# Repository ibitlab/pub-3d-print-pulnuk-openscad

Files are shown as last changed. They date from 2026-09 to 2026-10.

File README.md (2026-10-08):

**English** · [Українська](README.uk.md)

# Sealed enclosure for the KY-023 joystick

The KY-023 / HW-504 module costs a dollar and is open on every side: dust, dirt
and moisture go straight into the potentiometers. Here it lives in a closed box.
The only thing sticking out is the cap, and the motion is carried through a
printed TPU bellows boot that plugs the opening and re-centres the joystick at
the same time — the stock bell-shaped knob is no longer needed and comes off.

Fully parametric, a single OpenSCAD file, not one part needs supports.

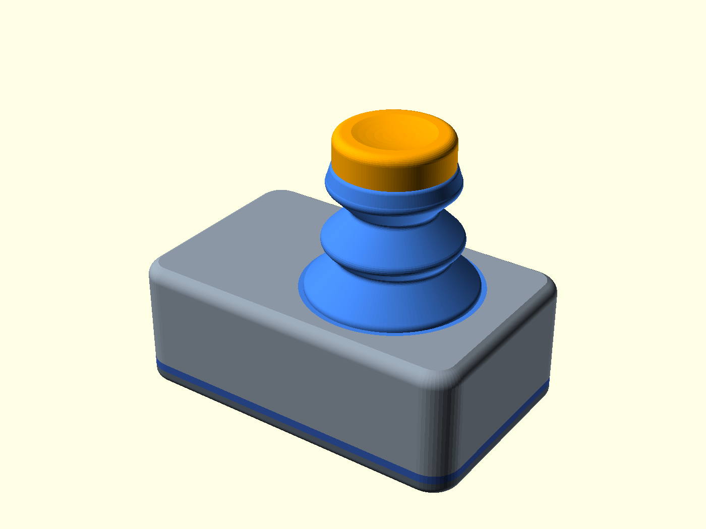
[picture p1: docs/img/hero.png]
Assembled enclosure


Box with lid: 62.4 × 39.1 × 23 mm, ≈53 mm tall including the cap.

| Printed and assembled on a KY-023 | The silicone mould, printed | TPU gasket and boot |
| --- | --- | --- |
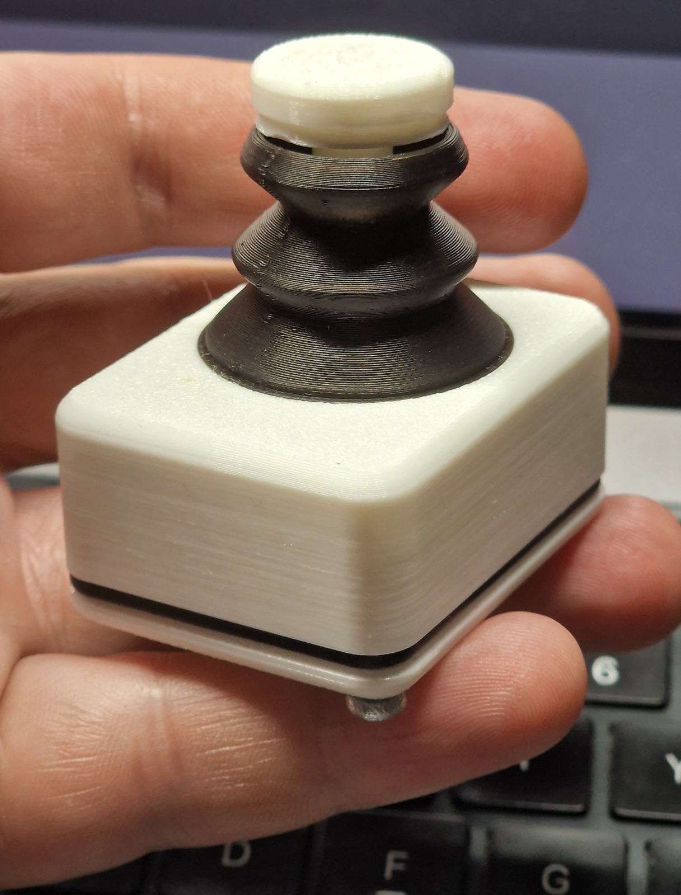
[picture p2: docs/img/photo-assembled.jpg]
The printed enclosure with the TPU boot and cap, in hand
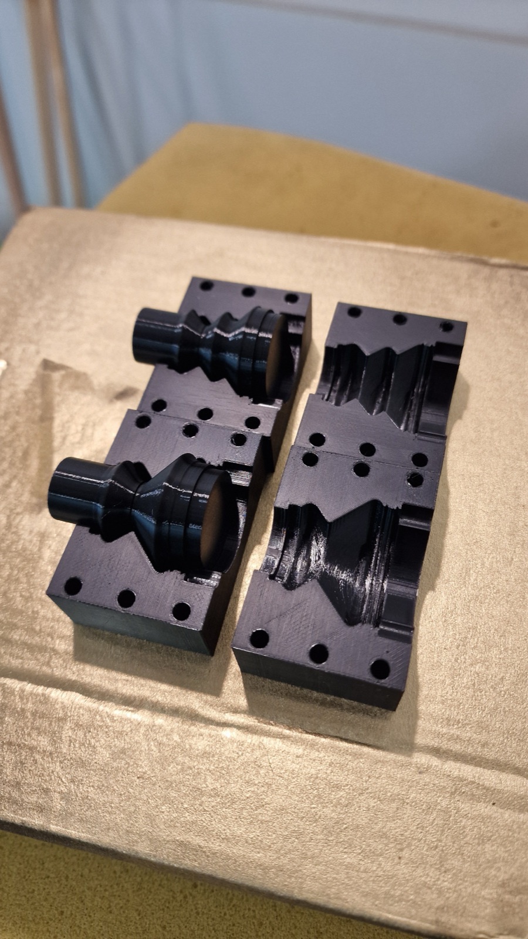
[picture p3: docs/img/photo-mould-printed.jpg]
The printed mould: shell halves and cores
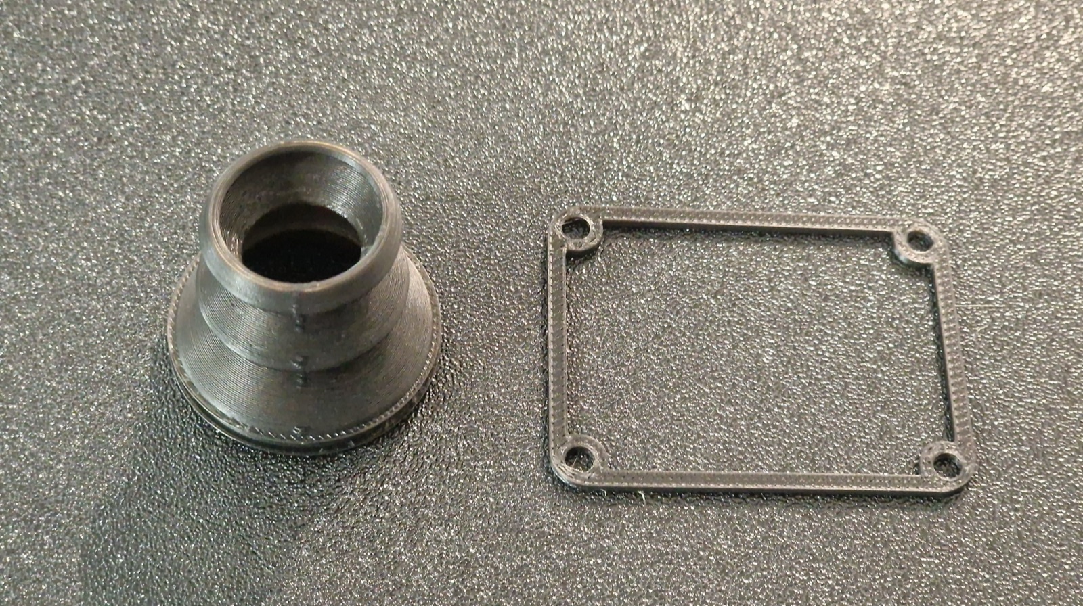
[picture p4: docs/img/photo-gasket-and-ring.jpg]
The printed TPU gasket and the boot with its expander ring
|  |  |  |

```
./render.sh     # every STL + PNG + the automatic checks, into versions/vNNN-.../
```

Next: **[PRINTING.md](PRINTING.md)** — printing, assembly, silicone casting ·
**[MODEL.md](MODEL.md)** — how it works and which parameters to turn.

---

## What's inside

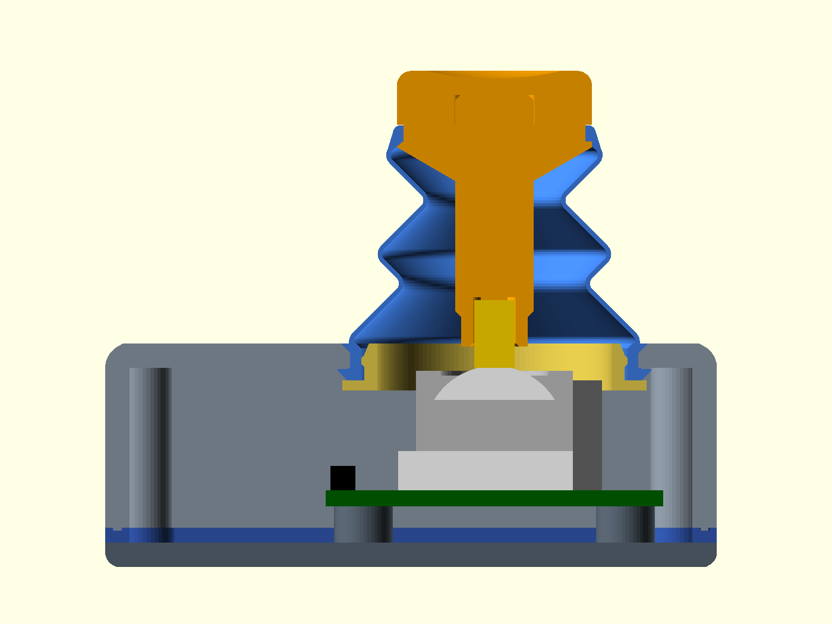
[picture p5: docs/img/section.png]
Section through the assembly


The PCB is screwed to standoffs on the **bottom** lid — lid and board go into the
box from below, so there is not a single screw and not a single joint on top.
Between the box rim and the lid sits a flat TPU gasket. The boot sits in the top
panel by its grommet, and is clamped at the top onto the groove of the cap stem.

Three joints, three different answers:

| Joint | What holds it |
|---|---|
| boot ↔ cap | a Ø1.6 bead stretched onto the stem groove with 6 % interference, covered by the glued-on head |
| boot ↔ box | the grommet cone seats into the panel countersink **flush** with it, the lip presses from below, and a rigid ring inside stops the grommet from pulling itself inward |
| box ↔ lid | a 0.8 × 0.5 rib on the box rim presses into the gasket groove; around each screw the rib is interrupted and the gasket is solid there |

Here is that grommet up close — the corrugation on the left, the expander ring in
yellow underneath, the box wall on the right:

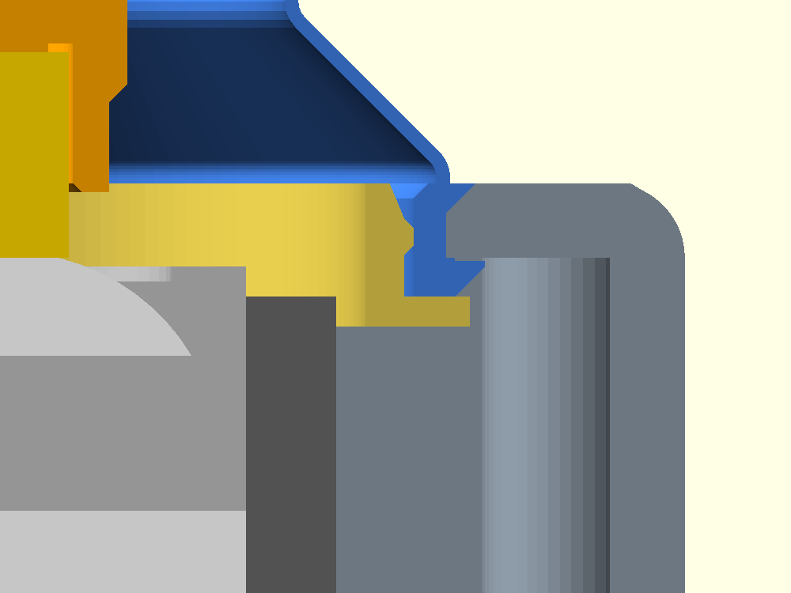
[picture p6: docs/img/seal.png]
Grommet in the panel


Nothing protrudes above the panel for anything to catch on.

## Why it re-centres

The boot is printed in exactly the shape it takes once installed, so its only
equilibrium is the centre. No spring required.

The whole trick is making it soft enough. The wall is printed in a **single nozzle
pass** — 0.46 mm, physically as thin as it gets — and stiffness grows as the cube
of thickness. The rest is down to the geometry of the folds: fold stiffness is
∝ 1/depth³, so one deep fold is softer than several shallow ones.

| `bellows = "v019"` — two folds | `bellows = "deep"` — one deep fold |
|---|---|
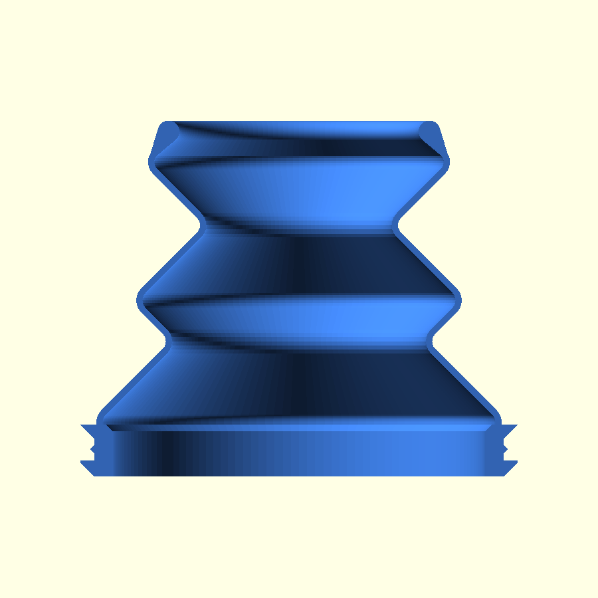
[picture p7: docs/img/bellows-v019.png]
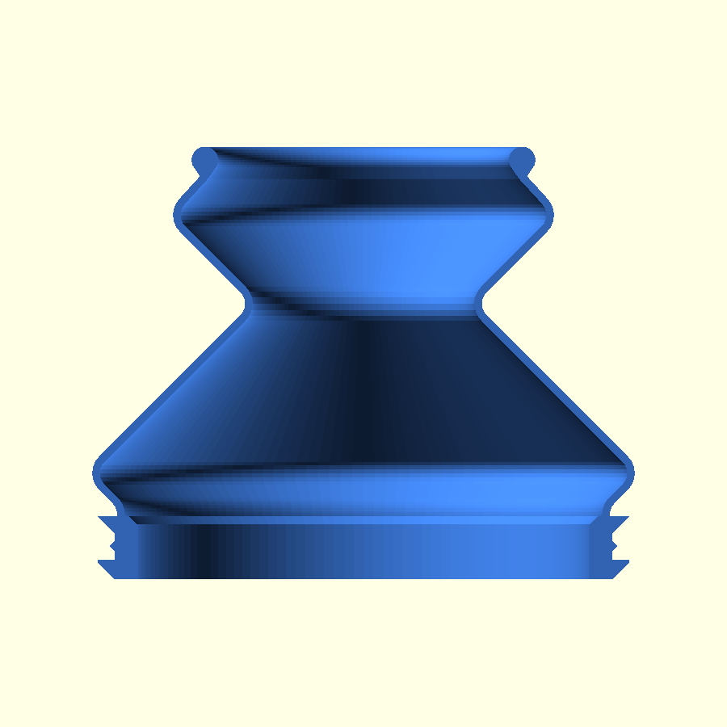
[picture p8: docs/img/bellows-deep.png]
|  |  |
| compliance index 0.46 · printed and verified on the module | index 0.91 — twice as soft on paper, not printed yet |

Both fit the same grommet, the same ring and the same stem groove — you can print
both and compare them on one module.

The model works this out itself and prints it to `ECHO` on every render:

```
ECHO: "Bellows "v019": meridian 27.9676 mm, rest chord 21.4529, last leg 33.4078 deg
       from vertical (keep <= 50), … compliance index 0.461043 (x 1/wall^3, higher = softer)"
ECHO: "At 25 deg: bead shifts 13.08 mm, … far-side stretch 3.95858 % (no stretch up to 21 deg)"
```

Up to 21° of tilt the far side of the boot only bends; stretch starts later and
reaches ~4 % at 25°. That is exactly why the bead is attached at the top of the
stem and not at the bottom, where the travel is half as long: those 13 mm of wall
length would cost 32 % stretch instead of 4, and stretch is no longer bending —
it is stiffness.

## Seven parts

| | | |
|---|---|---|
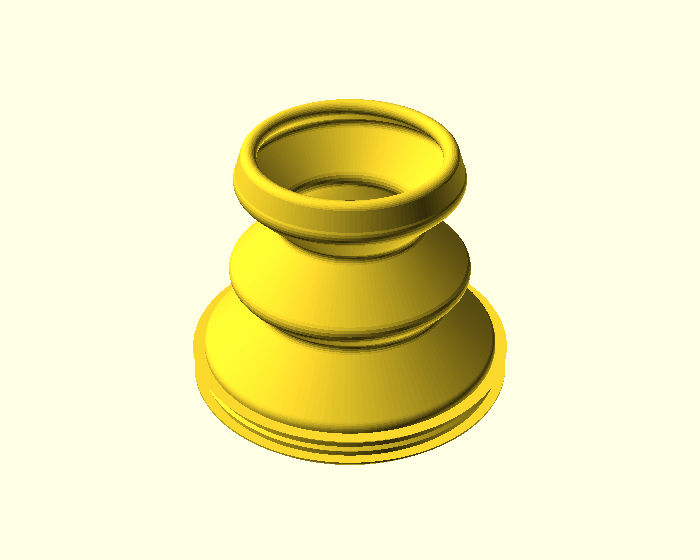
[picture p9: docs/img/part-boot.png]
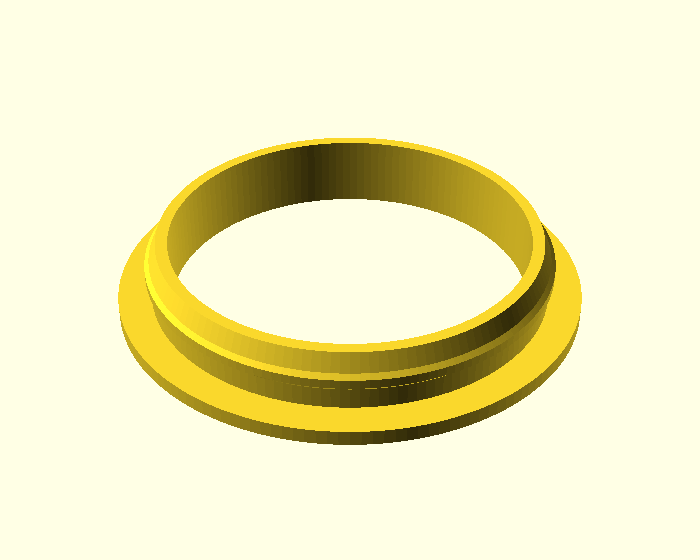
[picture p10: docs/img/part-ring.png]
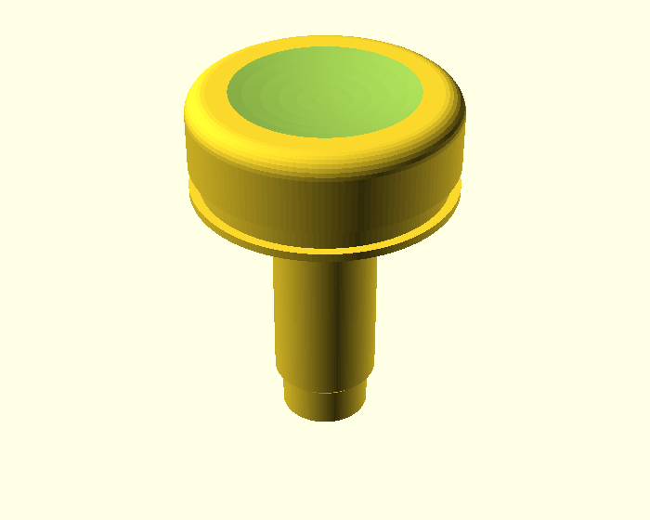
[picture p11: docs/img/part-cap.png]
|  **Boot with grommet** — TPU, single-pass wall |  **Expander ring** — goes into the grommet from inside |  **Cap** — head + stem, glued together |
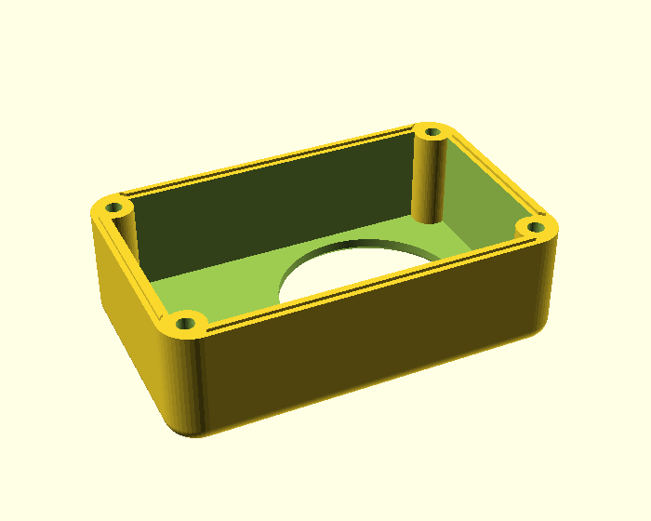
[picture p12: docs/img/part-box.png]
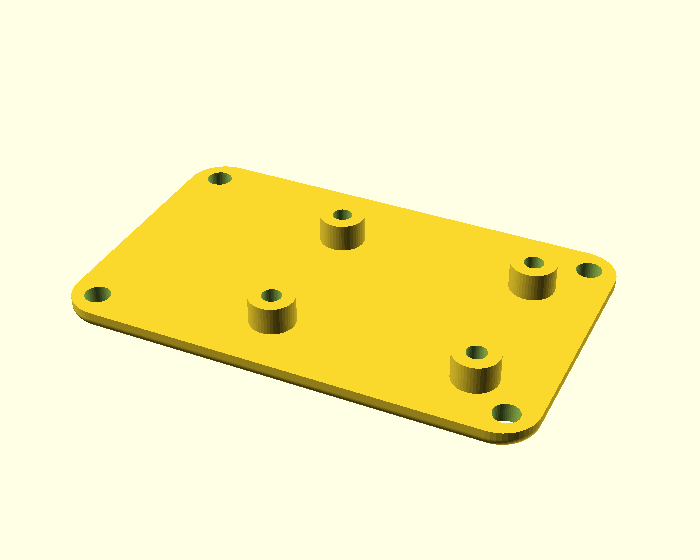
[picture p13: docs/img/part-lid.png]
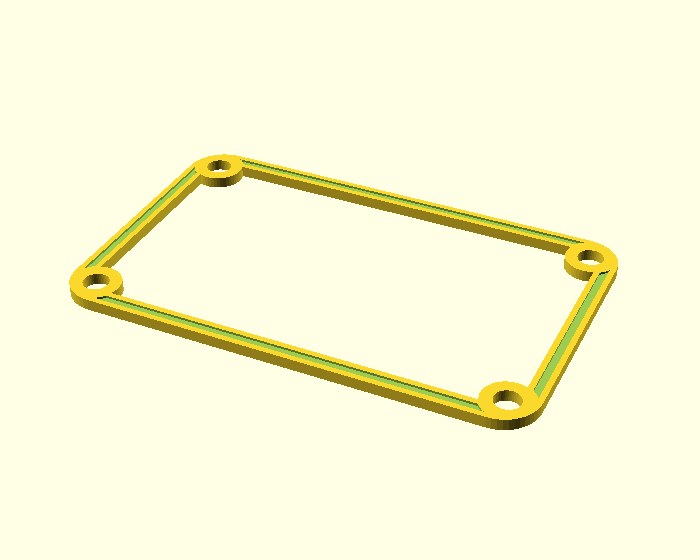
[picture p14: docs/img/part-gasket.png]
|  **Box** — sealing rib on the rim, 4 bosses |  **Lid** — PCB standoffs, enters from below |  **Gasket** — TPU, groove for the rib |

Plus a mock-up of the board — not for printing, it is there to check the joystick
and hole positions against your own module on screen:

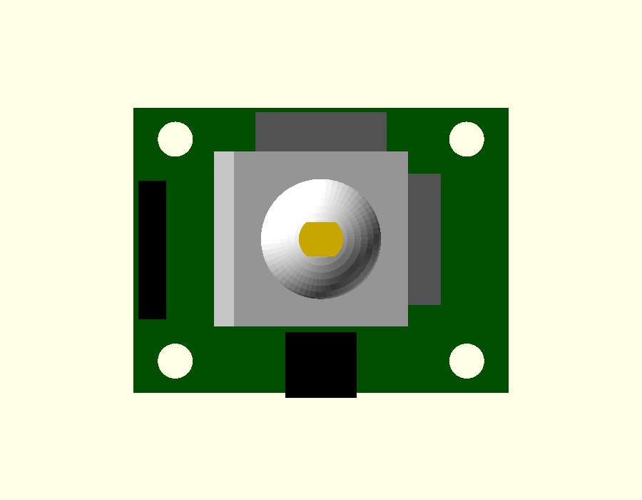
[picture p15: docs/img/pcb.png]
PCB mock-up


## Silicone instead of TPU

The printed TPU boot seals and re-centres, but in use it turned out too stiff
for this job, and a printed boot cannot get thinner than its 0.46 mm wall.
Silicone gets around that with the material instead: A20 is roughly 50 times
softer than TPU 95A, so even a 1.2 mm wall gives a boot about three times
softer. The geometry stays the same, so the next step is a boot cast in
platinum-cure silicone.

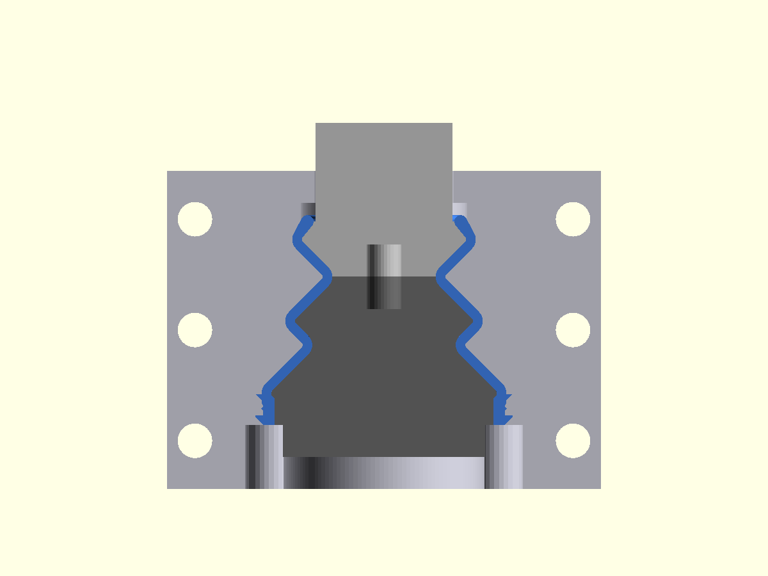
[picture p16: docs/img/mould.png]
Section through the mould


The mould is generated from the same model: two **identical** shell halves
(everything on the parting plane comes in ±X pairs, so one half rotated 180° is
the other), a core split at the waist of the corrugation — it cannot be pulled out
in one piece, being a barrel between two narrower openings — and pins. It is cast
bottom-up with a syringe: gravity will not fill a 1.2 mm annular gap over 28 mm of
height.

Procedure and quantities for silicone are in [PRINTING.md](PRINTING.md). The mould
is printed (photo at the top); the first cast is pending.

## How it grew

Same camera throughout, sources from `versions/` — a copy of the `.scad` for every
render lives there.

| v001 | v005 | v006 |
|---|---|---|
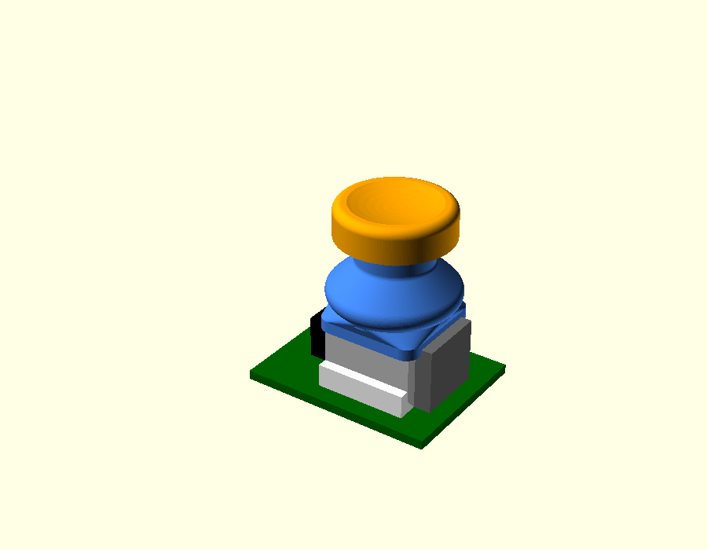
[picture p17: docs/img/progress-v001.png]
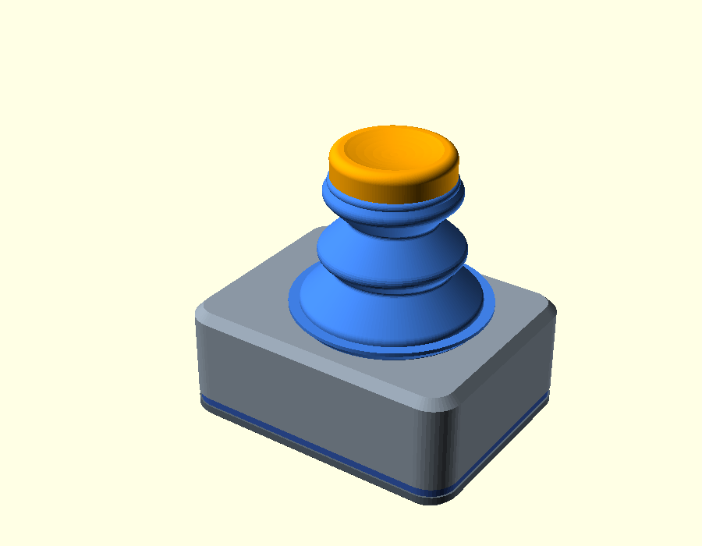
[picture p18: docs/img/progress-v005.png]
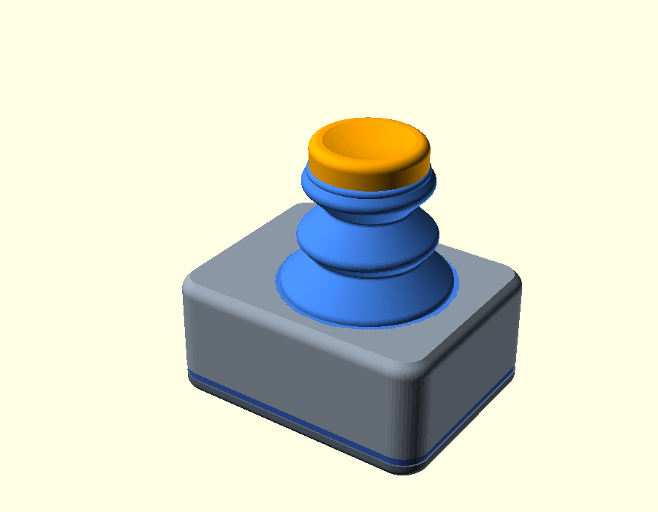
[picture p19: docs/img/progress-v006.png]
|  |  |  |
| Just an open boot over the joystick frame. No box yet, and no sealing either. | A grommet in the panel instead of a clamped sheet, lid moved to the bottom — no more screws on top. | **Printed.** The grommet cone seats into the countersink flush with the panel; the expander ring and the rounded edges appear. |

| v019 | now |
|---|---|
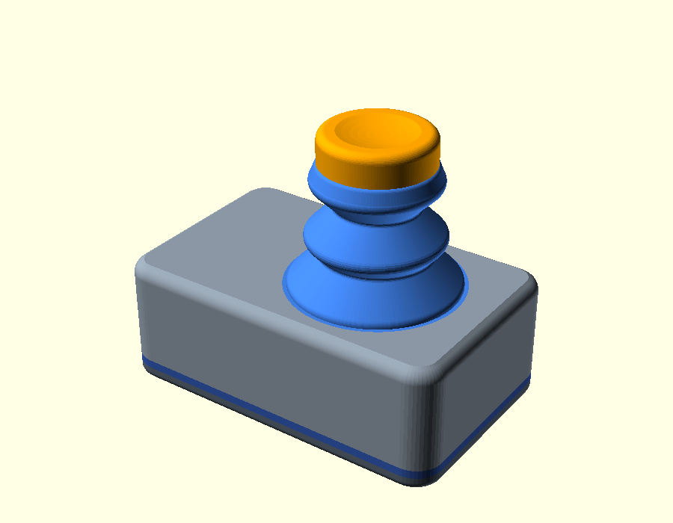
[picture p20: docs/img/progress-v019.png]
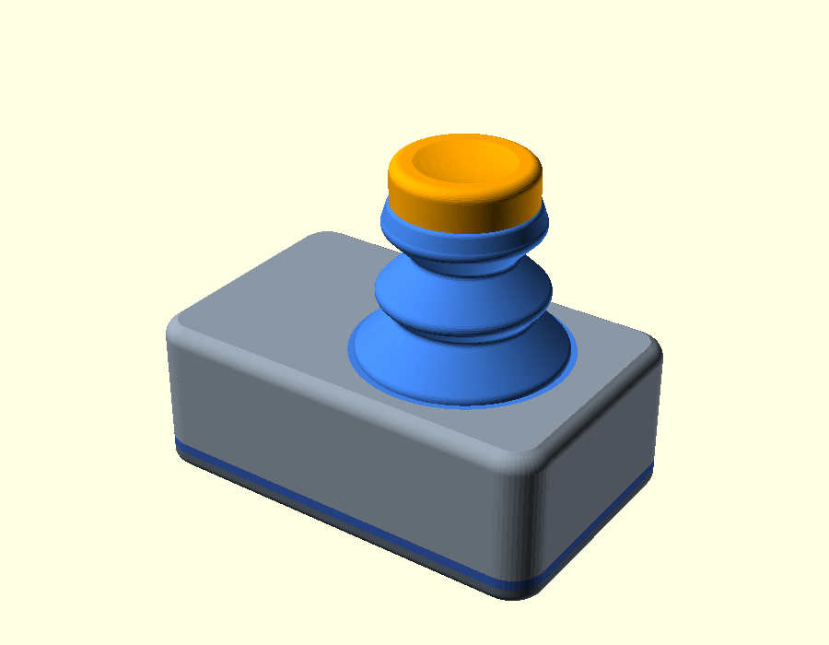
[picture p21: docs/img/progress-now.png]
|  |  |
| **Printed.** Measured joystick position on the board, two-part cap, bead moved onto the stem flange. | Two bellows profiles to choose from, a mould for casting, mesh checking on every render. |

The full history with the reasoning is at the end of [MODEL.md](MODEL.md).

## How this is verified

A render that looks right in a PNG proves nothing. So every `./render.sh` ends
with checks, and three more are run by hand:

| | |
|---|---|
| `check_mesh.py` | every STL must be **one closed body**: each edge in exactly two triangles, one body |
| `check_overhang.py` | slices the profile in 0.1 mm layers: islands, overhangs > 45°, cross-sections thinner than a slicer line |
| `check_fit.scad` | seven boolean tests of the mould — each exports what should not exist; ~0 mm³ should be left |
| `stl_volume.py` | volume, area and mean thickness 2·V/A — for a remainder that should have been zero, it is the thickness that matters, not the volume |
| `compare_versions.sh` | compares the STLs of two renders byte for byte: a part you did not touch must stay byte-identical |

This is not a formality. Two examples that brought these checks into being:

- **v021.** The boot wall was made a single 0.40 mm pass. The slicer silently
  dropped it at the bends, where the cross-section turns vertical, and empty
  layers appeared in the part. The cure is to model a single-pass wall as the
  slicer line width + 0.04 = 0.46 — and the `minw` check in `check_overhang.py`.
- **v026.** The mould shell would not slice, the slicer complained about
  non-manifold edges. The cause: the surface shared by the part and the core is
  drawn by different code — the wall by 24-gons, the core by true `offset()` arcs
  — and on the fold radii the two drifted apart by ~5 µm. Those slivers got
  pinched inside the cavity and left free 5 µm-thick rings in the shell. Invisible
  in a PNG, invisible in the volume. Hence `check_mesh.py` on every render.

And `compare_versions.sh` is the only honest way to tell "I rewrote the code" from
"I moved the geometry": neither a PNG nor a triangle count will tell you that.

## Status, honestly

- **Printed and assembled:** `v006` and `v019`. The default bellows profile is the
  one that is on the real module.
- **Not verified in plastic:** the `deep` bellows.
- **Printed, casting pending:** the mould for a platinum-cure silicone boot. The
  TPU boot works but is too stiff for this job, which is why the mould exists.
- **Not measured:** the mounting hole pitch of the board. The KY-023 grid is not in
  any datasheet, and the community mock-up contradicts itself (text 26.7 × 20.3,
  STL 26.5 × 19.0). The model uses 26.7 × 20.3 — for M3 standoffs a 1 mm miss is
  already critical, so **measure your own board before the first print**. It is two
  parameters.
- IP68 here means designed for IP68, not certified: nobody has put it under
  pressure and measured.

## What you need

OpenSCAD 2021+ (Manifold backend), Python 3 for the checks, a printer with a 0.4
nozzle and a bed from 70 × 50 mm. Filaments: TPU for the boot and the gasket,
PETG/ASA for the box and the lid, PLA/PETG for the ring and the cap. Fasteners:
4 × M3×6 and 4 × M3×10.

The full list, slicer settings, assembly order and silicone casting are in
[PRINTING.md](PRINTING.md).

## License

MIT — [LICENSE](LICENSE). Print it, measure your own board, change the parameters,
sell what you print; the only condition is keeping the copyright line. No
warranty of any kind: see "Status, honestly" above.

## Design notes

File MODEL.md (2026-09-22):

**English** · [Українська](MODEL.uk.md)

# The model: how it is built and what drives it

A reference for `ky023_boot.scad` — for whoever is going to edit the geometry. A
user who just prints needs only [PRINTING.md](PRINTING.md); for an overview of
the project — [README.md](README.md).

The whole model is one file: Customizer parameters in `/* [Name] */` groups,
derived geometry with `echo()` and WARNINGs, the part modules, and the `part`
selection at the end. The boot wall is `wall_lines` passes of the `nozzle_d` (0.4)
nozzle; at a single pass it is modelled as the slicer line width `line_w` (0.42)
+ 0.04 = 0.46 mm, because a cross-section thinner than a line gets dropped by the
slicer and empty layers appear at the bends (where the wall passes through
vertical).

## How it is sealed

| Joint | Solution |
|---|---|
| cap ↔ boot | a Ø18.5 × 1.7 groove on the cap stem flange: below it a flat Ø19.9 lip, above it the flat bottom of the glued-on head; the Ø1.6 bead at the top of the boot simply stretches onto the core of the groove (~6 %) before the head is glued on, so it never has to be pulled over the full head |
| boot ↔ box | the grommet: a lip under the panel (flat on top, 45° chamfer below), the body in a Ø29.4 opening with a rib, a 45° cone that seats into the panel countersink flush with it; from inside the box a rigid expander ring is inserted into the grommet from below. Its tube, Ø26.6, is 0.3 mm **narrower** than the printed grommet opening (which pulls inward anyway when the body is pressed into the panel opening) and only props the TPU up so the grommet cannot contract when the boot pulls; the only thing that presses is the Ø27.2 × 1.2 mm band with 45° chamfers, which sits in the panel opening under the grommet rib: there the 1.4 mm TPU wall is squeezed to 1.1 mm (21 %) over a height of just 1.2 mm, and that same band is what keeps the ring from falling out. The flange presses the grommet lip up against the panel. Nothing protrudes above the panel |
| box ↔ lid | the box is one piece (panel + walls + 4 corner bosses), open at the bottom; between the rim and the bottom lid is a flat 1.5 mm TPU gasket, flush with the body. The 0.8 × 0.5 mm sealing rib is on the **box rim**, not on the lid: the gasket goes onto it by its 1.0 × 0.3 mm groove and holds itself on the rim while you bring the lid in; the rib then presses a further 0.2 mm into the TPU. Around each screw the rib and the groove are interrupted over Ø7 — there the gasket is solid (the screws press hardest exactly there anyway, and a groove would leave webs thinner than a line) |
| cable | no hole (`gland_d = 0`): pot it with compound or drill it in place; `gland_d = 12.5` gives a teardrop hole for a PG7 in the −X wall |

## Re-centring

- The boot is symmetric and printed in the shape it has once installed, so its
  only equilibrium is the centre.
- The corrugation is switched with the `bellows` parameter; both options fit the
  same grommet, ring and stem groove:
  - **`v019`** (the default) — two folds, `fold_rises`; this is the very geometry
    that has been printed and verified on the module (the rebuilt STL is
    byte-identical to `versions/v019-*/ky023_boot.stl`). Compliance index 0.46;
  - **`deep`** — a short step outward above the panel, one very deep fold inward
    (10 mm, to within 2 mm of the neck) and back, `fold_dr`. Index 0.91, i.e.
    twice as soft on paper, but not printed yet.

  Both give ~28 mm of wall between the grommet and the stem groove: up to ~21° of
  tilt the far side only bends, at 25° the stretch is ~4 % (pulling back to
  centre). Fold stiffness is ∝ 1/depth³ — hence the difference in the indices.
  Shared levers: leg angle `leg_deg`, bend radii `fold_r_v019` / `fold_r_deep`.
- Why the bead is attached at the top and not at the bottom of the stem (where
  the travel is half as long): without supports the meridian has to keep rising
  at ≥45°, so the available wall length is ≈ height × 1.41, and a radial pattern
  adds nothing to it. Attaching at z 14 instead of 24 saves 4.3 mm of travel but
  costs 13 mm of wall: the stretch at 25° grows from ~4 % to 32 %, and stretch is
  no longer bending — it is stiffness. For the same reason many small waves are
  stiffer than one deep fold.
- The boot moves together with the head: the button simply compresses it by
  1.5 mm.
- What else reduces the resistance (strongest first): wall thickness (∝ t³:
  `wall_lines = 1` — 8 times softer, a 0.3 nozzle at 2 passes — 2.4 times); a
  softer filament (Elastan D160 is ~40–50 Shore D ≈ 95–98A, the hardest class of
  TPU; 85A would give another ~3 times); `leg_deg` 50 at a 0.15 layer — a slightly
  longer meridian and deeper folds for the same height. Beyond that — casting in
  silicone (see PRINTING.md).

## Parameters for your own module

The joystick position on the board and the hole grid are absent from the KY-023
datasheets, and the community mock-up (Printables 498437) contradicts itself
(text: holes 26.7 × 20.3; STL: 26.5 × 19.0 and the axis at the centre of the
board). So the model carries measured values, and the rest has to be measured:

| What | Parameter |
|---|---|
| board length × width | `pcb_l` 34.4, `pcb_w` 26.07 (measured) |
| axis position: centred lengthwise; 14.05 crosswise from the long edge with the button | `pcb_dx` 0, `pcb_dy = pcb_w/2 − 14.05` = −1.0 (measured) |
| hole pitch along and across the board, and their diameter | `pcb_hole_dx`, `pcb_hole_dy`, `pcb_hole_d` (26.7 × 20.3, Ø3.2 — **not measured**, for M3 standoffs a 1 mm difference is critical) |
| B — from the connector end to the centres of the nearest holes | `hole_dx = B + pcb_hole_dx/2 − pcb_l/2` (0 = grid centred on the board) |
| top of the potentiometers above the joystick's steel plate | `pot_top_z` (−1); the panel sits `panel_clear` higher, the grommet lip runs outside it (r ≥ 13.6) |
| the stem under the knob | `post_type` `dd`/`d`/`rect`, `post_d` 4.08, `post_flat` 3.12 (measured), `post_h` (7.2 per P3) |

Orientation in the model (from photos of the HW-504): the connector on the −X
end, the button on the −Y long edge, a potentiometer opposite it (+Y), the second
potentiometer facing the +X end. The gland hole is on −X. On render, `ECHO`
prints the distances to the ends and the standoff coordinates for checking. The
cap socket = stem + `socket_clear` 0.15 per side (a light interference fit; 0.2
if it will not go on, 0.1 if it wobbles), with a 0.4 chamfer at the entry.

## Box dimensions

Crosswise the box is centred on the joystick axis (the opening in the middle of
the panel, the board inside offset by 1 mm); lengthwise there is `cav_end` = 20 mm
of free length past the connector end, `cav_far` = 3 mm past the opposite one, and
`cav_side` = 3 mm at the sides. The cavity corner radius is derived from the box
corner (`cav_r = box_r − wall_t`), so the 2.5 mm wall — and with it the gasket on
top of it — is the same width everywhere, in the corners too.

The panel edges (R2.5) and the lid edges (R1.5) are rounded with an arc; both
edges lie on the bed while printing, so the arc starts at the angle
`edge_start_deg` (30°: the first ~0.8 mm are steeper than 45°, PETG holds that;
45 = safest, 0 = a full circle).

## Files and checks

| File | What it is |
|---|---|
| `ky023_boot.scad` | the parametric model of every part and of the assembly |
| `render.sh` | renders STLs and PNGs into a version folder, and at the end checks the mesh and the overhangs |
| `render_docs.sh` | the pictures for the README into `docs/img/` — the only generated thing kept in git (everything in `versions/` is ignored, and a GitHub visitor would otherwise never see the model). The progress gallery is rendered from the `.scad` copies in `versions/` with one camera |
| `check_mesh.py` | an STL must be one closed body: it welds vertices on a 0.1 µm grid and requires every edge to belong to exactly two triangles (fewer — a hole, more — two surfaces along a line) and the body to be single (`parts=N` if there are legitimately several) |
| `check_overhang.py` | printing without supports: it slices the profile (the y = 0 section) in 0.1 mm layers and checks that each layer rests on the previous one (islands, overhang angle); `flip` for parts printed upside down; `minw=W` catches cross-sections thinner than a slicer line |
| `check_fit.scad` | seven boolean tests of the mould (shell vs cores vs casting, the core halves against each other, cavity minus part and core) — each must come out ~0 mm³; run by hand, not from `render.sh` |
| `compare_versions.sh vNNN vMMM` | what exactly changed between two renders: it compares the STLs byte for byte, ignoring the version prefix in the name. The only honest way to tell "I rewrote the code" from "I moved the geometry" — a part you did not touch must stay byte-identical. Run it against the last `-printed` before printing anything again |
| `stl_volume.py` | volume (signed), area and mean thickness 2·V/A. For a boolean difference that should have come out empty, look at the thickness, not the volume: 2 µm is boolean-operation noise, 0.4 mm is a real part that will print as a loose fragment |
| `versions/vNNN-YYYYMMDD-HHMMSS/` | a copy of `.scad` + `.sh` + `.py`, the STLs and PNGs with the version number in front, and `render.log` |

`part` switches between: `boot`, `ring`, `cap_head`, `cap_stem`, `cap`
(assembled), `cap_section`, `box`, `lid`, `gasket`, `section`, `assembly`,
`assembly_section`, `mock`, `boot_cast`, `mould_shell`, `mould_core_lower`,
`mould_core_upper`, `mould_dowel`, `mould_pin`, `mould_section`, `mould_cavity`,
`mould_core_raw`. PNGs: `iso`, `side`, `top`, `section`, `section_deep`, `cap`,
`cap_section`, `box`, `box_inside`, `lid`, `gasket`, `ring`, `mock`, `mock_top`,
`assembly`, `assembly_section`, `base_section`.

### Version folders

`./render.sh` from the root creates a new `versions/vNNN-date-time/`; inside such
a folder the copy of the script re-renders it in place, next to its own copy of
the `.scad` — so an old version is reproducible even after incompatible changes
in the root. A folder is recognised by `vNNN-` and the date, and the rest of the
name can be anything; the `-printed` suffix is appended to the one that was
actually printed — that is the only marker that the geometry was verified in
plastic.

STLs and PNGs are named `vNNN_name`: the folder tells you where a file came from
only while the file is still in it, and the slicer shows nothing but the name.
The number goes in front because it is the start of the name that shows in a
narrow column; the number alone, without the date — with the date it is
unreadable, and the folder may be renamed later. The copied sources keep their
names: the folder and git identify them.

`.gitignore` ignores everything generated in `versions/*/` except the copied
`.scad`, `.sh` and `.py`. So in a fresh clone the version folders have no STLs,
and `compare_versions.sh` will not work there until you re-render both versions
yourself: go into the folder in question and run the copy of `render.sh` that
lives there — it reproduces its own version in place.

## The mould: why it is like that

- **The shell is a clamshell** of two halves: annular folds come out of them (at
  the parting plane the draft is zero, but there is no undercut — this is how
  bellows are cast).
- **The core is split at the waist** (the narrowest fold): it cannot be pulled out
  in one piece, because it is a barrel between two narrower openings. The upper
  half comes out upward through the bead (27 % stretch in `deep`, 20 % in `v019`),
  the lower one downward through the grommet (18 % / 3 %); silicone stretches
  400 %+, so this is nothing. The joint falls on an internal surface, so its flash
  touches no sealing surface.
- **The shell halves are identical**: every feature on the parting plane comes in
  ±X pairs, so one half rotated 180° is the other.
- **It is cast bottom-up.** Two Ø6 ports in the floor open onto the bottom face of
  the grommet lip: the syringe goes in one, and the other shows when the silicone
  has arrived. Air goes up and out through 4 Ø1.2 holes from the riser ring above
  the bead. Gravity will not fill a 1.2 mm annular gap over 28 mm of height — which
  is exactly why it goes in from below.
- **The riser**: the cavity runs 1.5 mm above the part, which is where the first
  dirty silicone and the remaining air collect; it is trimmed off afterwards.
- **No supports**: the shell prints parting-plane up — the cavity cross-section at
  print height is √(R(z)²−y²), i.e. it only widens going up while the body only
  narrows.
- **The casting wall** `cast_wall` = 1.2 mm: any thinner and the silicone simply
  will not flow through an annular gap 28 mm tall, and it tears on removal.

## History

`v001` — an open boot over the joystick frame; `v002`–`v003` — a sealed variant
with a clamped sheet (the bead loop would not print without supports, the sheet
sagged over the cavity); `v004` — the bead on the rim of the head; `v005` — a
grommet in the panel, the lid at the bottom, no gland hole; `v006` — the grommet
cone in a countersink instead of a flange, the expander ring, rounded edges;
`v007` — fixed the island under the bead (the teardrop runs along the leg), flat
cap top, automatic overhang checking in `render.sh`; `v008` — stem type as a
parameter (`dd`/`d`/`rect`), the default being round with two flats instead of the
P3 rectangle; `v009` — measured stem 4.08 / 3.12, 0.15 clearance, a chamfer at the
socket entry; `v010` — a two-part cap: the head prints top-up, the stem is glued
in; `v011` — measured joystick position on the board (34.4 × 26.07, axis 14.05
from the end with the button), connector and gland on +X, a parameter for the hole
grid offset; `v012` — a 20 mm compartment for the connector; `v013` — correct
orientation: button on the long edge (−Y), axis centred lengthwise and 14.05 from
the button edge crosswise, connector and compartment on −X; `v014` — a groove for
the rib in the gasket, the gasket flush with the body, wall thickness expressed in
nozzle passes; `v015` — smooth rounding of the box and lid edges (24 segments,
start angle as a parameter); `v016` — the expander ring is inserted from below,
from inside the box (a tube with a flange under the lip), the panel 1.3 mm above
the potentiometers; `v017` — the lip and the bead groove moved onto the stem
flange, the head is glued on top and covers the groove: the bead only stretches
6 %; `v018` — the box centred on the opening; `v019` — centring crosswise only
(where the board is offset), lengthwise the `cav_end` compartment only on the
connector side; `v020` — a softer corrugation: one deep fold (`fold_dr`), R1.2
chamfers, a vertical section under the bead (`bead_stub`), the compliance index in
`ECHO`; `v021` — an attempt at 1 pass (0.40 mm): the slicer dropped the wall at
the bends; `v022` — a single-pass wall = `line_w` + 0.04, thin cross-section
checking in `check_overhang.py`; `v023` — the expander ring no longer expands the
grommet over its whole length (the tube is 0.3 mm narrower than the printed
opening and only the 1.2 mm band under the grommet rib presses — in v022 it could
not be pushed in at all), the sealing rib moved from the lid to the box rim with
the gasket going onto it by its groove, the cavity corner derived from the box
corner, narrower rib/groove — 0.75 mm is left in the gasket corners instead of
0.34 (the slicer was dropping them); `v024` — the v019 corrugation returned to the
code as the `bellows = "v019"` option (the default) alongside the deep one, both
exported as separate STLs; `v025` — a mould for silicone casting for both
corrugations; `v026` — the v025 mould shell would not slice (the slicer complained
about non-manifold edges): the cavity was made of the part and the core, and their
shared internal surface is drawn by different code — the wall by `stroke2d` from
24-gons, the core by `offset()` with true arcs — and on the fold radii the two
drifted apart by ~5 µm; those slivers got pinched inside the cavity and left free
5 µm-thick rings in the shell. On top of that the closing rib `under2d` ran
diagonally and, at a negative `offset()`, cut off a 0.4 mm ring under the bead.
`check_mesh.py` was added to every render; `v027` — the version number in front of
the names of every STL and PNG.

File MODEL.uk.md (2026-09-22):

[English](MODEL.md) · **Українська**

# Модель: як вона влаштована і чим керується

Довідник по `ky023_boot.scad` — для того, хто правитиме геометрію. Користувачу,
який просто друкує, достатньо [PRINTING.uk.md](PRINTING.uk.md); оглядово про проект —
[README.uk.md](README.uk.md).

Уся модель — один файл: параметри Customizer у групах `/* [Назва] */`,
derived-геометрія з `echo()` і WARNING-ами, модулі деталей, у кінці вибір
`part`. Стінка сильфона = `wall_lines` проходів сопла `nozzle_d` (0.4); при
одному проході вона моделюється як ширина лінії слайсера `line_w` (0.42) + 0.04
= 0.46 мм, бо тонший за лінію переріз слайсер викидає і на згинах (де стінка
проходить через вертикаль) з'являються порожні шари.

## Як це герметизовано

| Стик | Рішення |
|---|---|
| ковпачок ↔ сильфон | канавка Ø18.5 × 1.7 на фланці штока ковпачка: знизу плоска губа Ø19.9, зверху її закриває плоский низ приклеєної головки; валик Ø1.6 на верху сильфона просто натягується на серцевину канавки (~6 %) до приклеювання головки, крізь повну головку його тягнути не треба |
| сильфон ↔ коробка | громмет: губа під панеллю (плоска зверху, фаска 45° знизу), тіло в отворі Ø29.4 з ребром, конус 45°, що сідає в зенківку панелі врівень з нею; зсередини коробки в громмет знизу вставляється жорстке розпірне кільце. Його труба Ø26.6 на 0.3 мм **вужча** за надрукований отвір громмета (отвір і так підтискається всередину, коли тіло тиснуть в отвір панелі) і лише підпирає TPU, щоб громмет не стягувався, коли сильфон тягне; тисне тільки поясок Ø27.2 × 1.2 мм із фасками 45°, що стає в отворі панелі під ребро громмета: там стінка TPU 1.4 мм тиснеться до 1.1 мм (21 %) на висоті лише 1.2 мм, і цей самий поясок утримує кільце від випадання. Фланець тисне губу громмета до панелі знизу. Над панеллю нічого не виступає |
| коробка ↔ кришка | коробка суцільна (панель + стінки + 4 бобишки в кутах), відкрита знизу; між бортиком і нижньою кришкою плоска TPU-прокладка 1.5 мм врівень із корпусом. Ущільнювальне ребро 0.8 × 0.5 мм — на **бортику коробки**, а не на кришці: прокладка надівається канавкою 1.0 × 0.3 мм на нього і сама тримається на бортику, поки заводиш кришку; ребро ще на 0.2 мм вдавлюється в TPU. Навколо кожного гвинта ребро і канавка перервані на Ø7 — там прокладка суцільна (гвинти й так тиснуть найсильніше саме там, а канавка лишала б перемички тонші за лінію) |
| кабель | отвору немає (`gland_d = 0`): заливка компаундом або свердлити за місцем; `gland_d = 12.5` дає отвір-краплю під PG7 у стінці −X |

## Повернення в центр

- Сильфон симетричний і надрукований у тій формі, яку має після встановлення,
  тому єдина рівновага — центр.
- Гофра перемикається параметром `bellows`; обидва варіанти стають на той
  самий громмет, кільце і канавку штока:
  - **`v019`** (за замовчуванням) — дві складки, `fold_rises`; це та сама
    геометрія, яку вже надрукували і перевірили на модулі (перебудований STL
    побайтово збігається з `versions/v019-*/ky023_boot.stl`). Індекс
    піддатливості 0.46;
  - **`deep`** — короткий крок назовні над панеллю, одна дуже глибока складка
    всередину (10 мм, до 2 мм від шийки) і назад, `fold_dr`. Індекс 0.91,
    тобто на папері удвічі м'якша, але ще не друкована.

  Обидві дають ~28 мм стінки між громметом і канавкою штока: до ~21° нахилу
  далекий бік лише згинається, на 25° розтяг ~4 % (тягне до центру).
  Жорсткість складки ∝ 1/глибина³ — звідси різниця індексів. Спільні важелі:
  кут ніг `leg_deg`, радіуси згинів `fold_r_v019` / `fold_r_deep`.
- Чому кріплення валика саме вгорі, а не внизу штока (де хід удвічі менший):
  без підтримок меридіан мусить увесь час підійматися під ≥45°, тож доступна
  довжина стінки ≈ висота × 1.41 і радіальний візерунок її не додає. Кріплення
  на z 14 замість 24 економить 4.3 мм ходу, але забирає 13 мм стінки: розтяг
  на 25° зростає з ~4 % до 32 %, а розтяг — це вже не згин, а жорсткість.
  З тієї ж причини багато дрібних хвиль твердіші за одну глибоку складку.
- Сильфон рухається разом із головкою: кнопка просто стискає його на 1.5 мм.
- Що ще зменшує опір (від найсильнішого): товщина стінки (∝ t³: `wall_lines
  = 1` — у 8 разів м'якше, сопло 0.3 при 2 проходах — у 2.4 раза); м'якший
  пластик (Elastan D160 — це ~40–50 Shore D ≈ 95–98A, найтвердіший клас TPU;
  85A дасть ще ~3 рази); `leg_deg` 50 при шарі 0.15 — трохи довший меридіан і
  глибші складки за ту саму висоту. Далі — лиття силіконом (див. PRINTING.uk.md).

## Параметри під свій модуль

Положення джойстика на платі і сітка отворів у datasheet-ах KY-023 відсутні,
а спільнотний макет (Printables 498437) суперечить сам собі (текст: отвори
26.7 × 20.3, STL: 26.5 × 19.0 і вісь у центрі плати). Тому в моделі стоять
виміряні значення, а решту треба доміряти:

| Що | Параметр |
|---|---|
| довжина × ширина плати | `pcb_l` 34.4, `pcb_w` 26.07 (виміряно) |
| положення осі: уздовж по центру; впоперек 14.05 від довгого краю з кнопкою | `pcb_dx` 0, `pcb_dy = pcb_w/2 − 14.05` = −1.0 (виміряно) |
| крок отворів уздовж і впоперек плати, їх діаметр | `pcb_hole_dx`, `pcb_hole_dy`, `pcb_hole_d` (26.7 × 20.3, Ø3.2 — **не виміряно**, для стійок M3 різниця в 1 мм критична) |
| B — від торця з роз'ємом до центрів ближніх отворів | `hole_dx = B + pcb_hole_dx/2 − pcb_l/2` (0 = сітка по центру плати) |
| верх потенціометрів над сталевою пластиною джойстика | `pot_top_z` (−1); панель стоїть на `panel_clear` вище, губа громмета йде ззовні (r ≥ 13.6) |
| шток під шапкою | `post_type` `dd`/`d`/`rect`, `post_d` 4.08, `post_flat` 3.12 (виміряно), `post_h` (7.2 за P3) |

Орієнтація в моделі (за фото HW-504): роз'єм на торці −X, кнопка на довгому
краю −Y, навпроти неї потенціометр (+Y), другий потенціометр дивиться на торець
+X. Отвір сальника на −X. `ECHO` при рендері друкує відстані до торців і
координати стійок для перевірки. Гніздо ковпачка = шток + `socket_clear` 0.15
на бік (легкий натяг; 0.2 якщо не налазить, 0.1 якщо бовтається), на вході
фаска 0.4.

## Габарити коробки

Впоперек коробка центрована на осі джойстика (отвір посередині панелі, плата
всередині зміщена на 1 мм); вздовж — за торцем із роз'ємом `cav_end` = 20 мм
вільної довжини, за протилежним `cav_far` = 3 мм, збоку `cav_side` = 3 мм. Кут
порожнини виводиться з кута коробки (`cav_r = box_r − wall_t`), тож стінка
2.5 мм — а з нею і прокладка на ній — однакової ширини скрізь, у кутах теж.

Ребра панелі (R2.5) і кришки (R1.5) заокруглені дугою; обидва ребра лежать на
столі при друці, тому дуга починається під кутом `edge_start_deg` (30°: перші
~0.8 мм крутіші за 45°, PETG це тримає; 45 = найбезпечніше, 0 = повне коло).

## Файли і перевірки

| Файл | Що це |
|---|---|
| `ky023_boot.scad` | параметрична модель усіх деталей і збірки |
| `render.sh` | рендер STL і PNG у версійну папку, наприкінці — перевірка сітки і навісів |
| `render_docs.sh` | картинки для README у `docs/img/` — єдине згенероване, що лежить у гіті (усе в `versions/` ігнорується, і відвідувач GitHub інакше не побачив би моделі). Галерея прогресу рендериться з копій `.scad` у `versions/` однією камерою |
| `check_mesh.py` | STL має бути одним замкненим тілом: зварює вершини по сітці 0.1 мкм і вимагає, щоб кожне ребро належало рівно двом трикутникам (менше — дірка, більше — дві поверхні вздовж лінії) і щоб тіло було одне (`parts=N`, якщо їх законно кілька) |
| `check_overhang.py` | друк без підтримок: ріже профіль (переріз y = 0) шарами по 0.1 мм і перевіряє, що кожен шар спирається на попередній (острови, кут навісу); `flip` для деталей, що друкуються догори дном; `minw=W` ловить перерізи тонші за лінію слайсера |
| `check_fit.scad` | сім булевих тестів молда (мушля vs стрижні vs відливка, половини стрижня між собою, порожнина мінус деталь і стрижень) — кожен має дати ~0 мм³; запускається вручну, не з `render.sh` |
| `compare_versions.sh vNNN vMMM` | що саме змінилось між двома рендерами: порівнює STL побайтово, ігноруючи префікс версії в імені. Єдиний чесний спосіб відрізнити «переписав код» від «зрушив геометрію» — деталь, якої не торкались, мусить лишитись байт-у-байт. Ганяти проти останньої `-printed` перед тим, як щось друкувати знову |
| `stl_volume.py` | об'єм (зі знаком), площа і середня товщина 2·V/A. Для булевої різниці, що мала вийти порожньою, дивитись треба на товщину, а не на об'єм: 2 мкм — похибка булевої операції, 0.4 мм — реальна деталь, що надрукується вільним уламком |
| `versions/vNNN-YYYYMMDD-HHMMSS/` | копія `.scad` + `.sh` + `.py`, STL і PNG з номером версії спереду, `render.log` |

`part` перемикає: `boot`, `ring`, `cap_head`, `cap_stem`, `cap` (зібраний),
`cap_section`, `box`, `lid`, `gasket`, `section`, `assembly`,
`assembly_section`, `mock`, `boot_cast`, `mould_shell`, `mould_core_lower`,
`mould_core_upper`, `mould_dowel`, `mould_pin`, `mould_section`,
`mould_cavity`, `mould_core_raw`. PNG: `iso`, `side`, `top`, `section`,
`section_deep`, `cap`, `cap_section`, `box`, `box_inside`, `lid`, `gasket`,
`ring`, `mock`, `mock_top`, `assembly`, `assembly_section`, `base_section`.

### Версійні папки

`./render.sh` з кореня створює нову `versions/vNNN-дата-час/`; усередині такої
папки копія скрипта перерендерює її на місці, поруч зі своєю копією `.scad` —
тож стара версія відтворюється й після несумісних змін у корені. Папка
розпізнається за `vNNN-` і датою, решту назви можна дописувати довільно;
суфікс `-printed` дописують до тієї, яку реально надрукували, — це єдина
ознака, що геометрію перевіряли в пластику.

STL і PNG називаються `vNNN_ім'я`: папка каже, звідки файл, лише поки файл у
ній лежить, а в слайсері видно тільки ім'я. Номер спереду, бо саме початок
імені видно у вузькій колонці; сам лише номер, без дати — з датою не
читається, а папку згодом можуть перейменувати. Скопійовані сорси імені не
міняють: їх визначає папка і git.

`.gitignore` ігнорує все згенероване у `versions/*/`, крім скопійованих
`.scad`, `.sh` і `.py`. Тому у свіжому клоні версійні папки порожні на STL, і
`compare_versions.sh` там не працює, доки обидві версії не перерендериш у себе:
зайти в потрібну папку і запустити тамтешню копію `render.sh` — вона відтворює
свою версію на місці.

## Молд: чому саме так

- **Мушля — кламшел** із двох половин: кільцеві складки з них виходять (біля
  площини розняття ухил нульовий, але піднутрення немає — так і ллють сильфони).
- **Стрижень розрізаний по талії** (найвужча складка): суцільним його не
  вийняти, бо він бочка між двох вужчих отворів. Верхня половина виходить угору
  крізь валик (розтяг 27 % у `deep`, 20 % у `v019`), нижня — вниз крізь громмет
  (18 % / 3 %); силікон тягнеться на 400 %+, тож це дрібниця. Стик припадає на
  внутрішню поверхню, тож його облой не чіпає жодного ущільнення.
- **Половини мушлі однакові**: усі елементи на площині розняття стоять парами
  ±X, тож одна половина, повернута на 180°, і є друга.
- **Ллється знизу вгору.** Два порти Ø6 у дні виходять на нижню площину губи
  громмета: в один — шприц, у другому видно, коли силікон дійшов. Повітря йде
  вгору і виходить крізь 4 отвори Ø1.2 з кільця-ризера над валиком. Гравітацією
  кільцеву щілину 1.2 мм на 28 мм висоти не залити — саме тому знизу.
- **Ризер**: порожнина йде на 1.5 мм вище за деталь, туди збирається перше
  брудне і рештки повітря; потім обрізається.
- **Без підтримок**: мушля друкується площиною розняття догори — переріз
  порожнини на висоті друку це √(R(z)²−y²), тобто вона лише ширшає догори, а
  тіло лише звужується.
- **Стінка відливки** `cast_wall` = 1.2 мм: тонше силікон просто не протече
  крізь кільцеву щілину на 28 мм висоти і рветься при вийманні.

## Історія

`v001` — відкритий пильник на рамку джойстика; `v002`–`v003` — герметичний
варіант із затиснутим листом (петля валика не друкувалась без підтримок, лист
провисав над порожниною); `v004` — валик по ободу головки; `v005` — громмет у
панелі, кришка знизу, без отвору сальника; `v006` — конус громмета в зенківці
замість фланця, розпірне кільце, заокруглені ребра; `v007` — виправлено острів
під валиком (крапля йде вздовж ноги), плоский верх ковпачка, автоматична
перевірка навісів у `render.sh`; `v008` — тип штока параметром (`dd`/`d`/`rect`),
дефолт круглий з двома лисками замість прямокутника P3; `v009` — виміряний шток
4.08 / 3.12, зазор 0.15, фаска на вході гнізда; `v010` — ковпачок із двох
частин: головка друкується верхом догори, шток вклеюється; `v011` — виміряне
положення джойстика на платі (34.4 × 26.07, вісь 14.05 від торця з кнопкою),
роз'єм і сальник на +X, параметр зсуву сітки отворів; `v012` — відсік 20 мм для
роз'єму; `v013` — правильна орієнтація: кнопка на довгому краю (−Y), вісь по
центру вздовж плати і 14.05 від краю з кнопкою впоперек, роз'єм і відсік на −X;
`v014` — канавка під ребро у прокладці, прокладка врівень із корпусом, товщина
стінки в проходах сопла; `v015` — плавне заокруглення ребер коробки і кришки
(24 сегменти, кут старту параметром); `v016` — розпірне кільце вставляється
знизу, зсередини коробки (труба з фланцем під губу), панель на 1.3 мм над
потенціометрами; `v017` — губа і канавка валика перенесені на фланець штока,
головка приклеюється зверху і закриває канавку: валик натягується лише на 6 %;
`v018` — коробка центрована на отворі; `v019` — центрування лише впоперек (де
плата зміщена), вздовж відсік `cav_end` тільки з боку роз'єму; `v020` — м'якша
гофра: одна глибока складка (`fold_dr`), фаски R1.2, вертикальна ділянка під
валиком (`bead_stub`), індекс піддатливості в `ECHO`; `v021` — спроба з 1
проходом (0.40 мм): слайсер викидав стінку на згинах; `v022` — стінка одного
проходу = `line_w` + 0.04, перевірка тонких перерізів у `check_overhang.py`;
`v023` — розпірне кільце більше не розпирає громмет по всій довжині (труба на
0.3 мм вужча за надрукований отвір, тисне лише поясок 1.2 мм під ребром
громмета — v022 було взагалі не запхати), ребро ущільнення перенесене з кришки
на бортик коробки і прокладка канавкою надівається на нього, кут порожнини
виведений з кута коробки, вужчі ребро/канавка — у кутах прокладки лишається
0.75 мм замість 0.34 (слайсер їх викидав); `v024` — гофра v019 повернена в код
як варіант `bellows = "v019"` (за замовчуванням) поруч із глибокою `deep`,
обидві експортуються окремими STL; `v025` — молд під лиття силіконом для обох
гофр; `v026` — мушля молда з v025 не різалась (слайсер лаявся на non-manifold
edges): порожнина складалась із деталі й стрижня, а їхню спільну внутрішню
поверхню малює різний код — стінку `stroke2d` з 24-кутників, стрижень
`offset()` справжніми дугами, — і на радіусах складок вони розходились на
~5 мкм; ці щілини защемлювались у порожнині й лишали в мушлі вільні кільця
товщиною 5 мкм. Плюс замикаюче ребро `under2d` йшло по діагоналі й при
від'ємному `offset()` зрізало 0.4 мм кільце під валиком. Додано `check_mesh.py`
на кожен рендер; `v027` — номер версії спереду в іменах усіх STL і PNG.

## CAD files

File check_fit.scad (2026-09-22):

// Fit test for the casting mould: pieces that have to come apart must share no
// material, and the cavity must be exactly the part plus the core. Each case
// renders what should not exist, so every export must measure ~0 mm3 (empty
// STLs are normal; OpenSCAD may also emit a few zero-volume triangles where
// two surfaces touch, which is why the answer is a volume and not a file size).
//
//   for t in 1 2 3 4 5 6 7; do
//       rm -f /tmp/fit.stl                       # an empty result writes no
//       openscad -o /tmp/fit.stl --export-format binstl -D t=$t \
//                -D 'bellows="v019"' check_fit.scad
//       python3 stl_volume.py /tmp/fit.stl       # file at all, so clear it or
//   done                                         # the last one gets measured twice
//
// This file has to stay next to ky023_boot.scad: include resolves relative to
// *the including file*, not to the working directory (so any cwd is fine, but a
// copy of this file somewhere else is not, unless OPENSCADPATH points here).
// A failed include leaves every module undefined and renders an empty STL -
// which passes all seven tests without a word. The assert below turns that
// silent pass into a loud failure.
//
// The model is used as a library: include pulls in every module, and assigning
// part afterwards overrides the selector inside it so nothing is drawn twice.
// Everything is in model coordinates (the mould assembled), not in the print
// placement the mould_* STLs are exported in.
include <ky023_boot.scad>
part = "none";

assert(!is_undef(cast_wall), "ky023_boot.scad was not included - keep this file next to it");
assert(!is_undef(t), "run with -D t=1..7");

if (t == 1) intersection() { mould_shell(); mould_core(true); }         // shell vs upper core
else if (t == 2) intersection() { mould_shell(); mould_core(false); }   // shell vs lower core
else if (t == 3) intersection() { mould_shell(); boot(cast_wall); }     // shell vs the casting
else if (t == 4) intersection() { mould_core(true); mould_core(false); } // the two core halves
else if (t == 5) intersection() { mould_core(true); boot(cast_wall); }
else if (t == 6) intersection() { mould_core(false); boot(cast_wall); }
// What the cavity holds over and above the part and the core. Not zero by
// design: the core is welded mould_weld into the wall (filled2d) and the clip
// runs eps into the riser, so this is a thin film plus a 0.01 mm disc - check
// the mean thickness, not the volume.
else if (t == 7) difference() { mould_cavity(); boot(cast_wall); mould_core_raw(); }

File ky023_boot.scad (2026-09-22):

// =====================================================================
//  KY-023 thumb-joystick sealed (IP68) enclosure:
//  TPU bellows boot + expander ring + rigid cap + hermetic box + lid
// =====================================================================
//
//  Parts (all printed):
//    boot    TPU      grommet that sits in the countersunk hole of the box
//                     top panel (flush), conical bellows, top sealing bead
//    ring    PLA/PETG expander pushed into the grommet bore from inside the
//                     box (before the lid goes on): its tube backs the bore so
//                     the grommet cannot collapse inwards when the bellows
//                     pulls, one short band squeezes the TPU into the panel
//                     hole and holds the ring up, and its flange presses the
//                     grommet lip against the panel underside
//    cap     PLA/PETG replaces the stock 26.8 mm bell knob; two prints:
//                     cap_stem (socket for the post, neck, flange with the
//                     bead lip + groove core, plug) and cap_head (disc glued
//                     onto the plug; its flat underside closes the groove).
//                     The boot bead is pushed onto the groove core (~6 %
//                     stretch) before the head is glued on, so it never has
//                     to pass over the full head diameter
//    box     PETG/ASA one piece: top panel with the boot hole, walls, four
//                     corner screw bosses, sealing rib on the rim; open at
//                     the bottom
//    lid     PETG/ASA bottom plate with the PCB standoffs, inner face flat
//    gasket  TPU      flat frame between the box rim and the lid, with a
//                     groove on its box side that hangs it on the rim rib
//                     while the lid goes on (exported groove up)
//
//  Sealing path: water -> head-rim groove (bead) -> bellows wall -> grommet
//                cone in the panel countersink + body squeezed between the
//                expander ring and the hole (ridge) + lip under the panel
//                -> box walls -> gasket under the rim rib.
//  No cable hole by default (gland_d = 0): pot the cable or drill on site.
//
//  Return-to-centre: the bellows is symmetric and printed in the exact
//  shape it has when installed, so the only equilibrium is the centre.
//  Two fold patterns are selectable with "bellows": "v019" (two folds, the
//  one that was printed and tested on the module) and "deep" (one deep fold,
//  softer on paper). They share the grommet, bead, cap groove and ring, so
//  both fit the same hardware. The ECHO output reports the wall length, up to
//  which tilt the far side only bends and how much it stretches at tilt_deg
//  (stretch pulls towards the centre, never away).
//
//  Printability (no supports anywhere):
//    boot   grommet down: lip chamfer, ridge and cone at 45 deg, inner
//           retaining lip 45 deg, bellows legs <= leg_deg, bead teardrop
//    ring   flange down: straight tube, 45 deg flanks on the band, the tip
//           that enters first tapers inwards
//    cap_head  underside on the bed: true round-over and finger dish on
//              top, blind plug hole bridged (8 mm)
//    cap_stem  boss (socket) on the bed, brim: socket ceiling is a small
//              bridge, flange underside is a flange_cone_deg cone
//    box    upside down (top panel on the bed): bosses rise from the panel,
//           countersink and panel edge round-over stay within 45 deg, the rim
//           rib is the last few layers
//    lid    outer face down: standoffs print upwards
//  Bed-side edges are "printable rounds": 45 deg for the first layers,
//  then a true arc into the vertical face.
//
//  Coordinates: stick axis = Z, Z = 0 is the top of the joystick's steel
//  plate; the box panel sits panel_clear above the pot tops. mm.
//
//  Check on your module with calipers: PCB size and hole grid, the stick
//  offset from the PCB centre (pcb_dx), pot tops (pot_top_z, must stay
//  below the panel) and above all the centre post (post_type, post_d,
//  post_flat, post_h) - clones differ from the P3/SparkFun drawing.
// =====================================================================

/* [Part] */
// What to render / export
part = "boot"; // [boot, ring, cap_head, cap_stem, cap, cap_section, box, lid, gasket, section, assembly, assembly_section, mock, boot_cast, mould_shell, mould_core_lower, mould_core_upper, mould_dowel, mould_pin, mould_section, mould_cavity, mould_core_raw]

/* [Printing] */
// Nozzle / line width
nozzle_d = 0.4; // [0.3:0.1:0.6]
// Bellows wall thickness in perimeters (passes) of the nozzle
wall_lines = 1; // [1:1:4]
// Slicer extrusion line width (usually nozzle + 0.02..0.05). A single-line
// wall is modelled a hair wider than this, otherwise the slicer drops the
// wall where it passes through vertical (fold crests) -> empty layers
line_w = 0.42; // [0.3:0.01:0.7]
// Segments per revolution
fn_round = 144; // [48:12:240]

/* [Joystick module (measure with calipers)] */
// Square steel frame width (mock-up only)
frame_w = 16.0;
// Top plate height above the PCB
plate_h = 12.2;
// Round opening in the top plate (mock-up only)
opening_d = 11.0;
// Gimbal centre relative to the plate top
pivot_z = -6.7;
// Centre post the cap presses onto. MEASURE IT: "dd" = round with two flats
// (typical KY-023 clone, ~4.0 mm, 3.0 across flats), "d" = round with one
// flat (Alps RKJXV: 4.0 / 3.0), "rect" = 1.15 x 1.85 (P3 America 802 /
// SparkFun COM-09032 drawing, Detail A-A')
post_type = "dd"; // [dd, d, rect]
// Round post: diameter and across-flats (d: flat-to-round distance)
post_d = 4.08;
post_flat = 3.12;
// Rectangular post: width x length
post_w = 1.15;
post_l = 1.85;
// Exposed post height above the plate
post_h = 7.2;
// Pot tops relative to the plate top (must stay under the panel hole)
pot_top_z = -1.0;
// PCB size and thickness (measured 34.4 x 26.07)
pcb_l = 34.4;
pcb_w = 26.07;
pcb_t = 1.6;
// Layout (from the HW-504 / KY-023 photo): the header sits on the -X short
// edge; the tact switch is on the -Y long edge with one pot opposite it on
// +Y; the other pot faces the +X short edge.
// PCB centre relative to the stick axis. Measured: along the 34.4 mm length
// the stick is centred (pcb_dx = 0); across the width it is 14.05 mm from
// the switch-side long edge -> pcb_dy = 14.05 - pcb_w / 2 = ... negative
// because the switch edge is on -Y: pcb_dy = pcb_w / 2 - 14.05
pcb_dx = 0;
pcb_dy = 26.07 / 2 - 14.05;
// PCB mounting hole grid (along / across the PCB) and hole diameter. NOT
// measured yet: the mock-up's text says 26.7 x 20.3, its STL 26.5 x 19.0
pcb_hole_dx = 26.7;
pcb_hole_dy = 20.3;
pcb_hole_d = 3.2;
// Hole grid centre relative to the PCB centre along the length (+ = away
// from the header): B = header-end edge to the nearest hole centres, then
// hole_dx = B + pcb_hole_dx / 2 - pcb_l / 2
hole_dx = 0;
// Working tilt of the stick
tilt_deg = 25; // [15:35]
// Stick push-down (button) travel
push_travel = 1.5;
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

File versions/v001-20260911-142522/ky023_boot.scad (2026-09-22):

// =====================================================================
//  KY-023 thumb-joystick dust boot (TPU) + rigid replacement cap
// =====================================================================
//
//  Why a replacement cap: the stock KY-023 knob is a 26.8 mm bell that
//  already overhangs the 16 mm frame and the 26 mm PCB, so no gaiter fits
//  under it.  The boot below lives inside the cap-head footprint instead:
//
//      square stretch skirt on the 16 mm steel frame
//        -> solid square-to-round base ("shelf") on the top plate
//        -> one deep rounded fold, 0.8 mm wall (2 x 0.4 mm perimeters)
//        -> floating collar around the dia 8 neck of the printed cap
//
//  Return-to-centre is guaranteed by geometry, not by softness:
//    * the collar clears the neck radially so NOTHING touches the stick
//      inside the +/- deadband_deg cone -> zero preload, friction or bias
//      at rest; only beyond ~7 deg does the neck drag the collar;
//    * the collar top sits head_gap below the cap head, so pushing the
//      stick (button) never loads the boot;
//    * printed shape == installed shape (only the skirt is stretched, and
//      that stretch is axisymmetric and never reaches the stick).
//
//  Coordinates: Z = 0 is the top surface of the joystick's steel top
//  plate, Z up, stick axis = Z axis, gimbal pivot at Z = pivot_z.
//  Everything is in millimetres.
//
//  Before printing, check with calipers on your module:
//    frame_w   (square steel frame width, nominal 16.0)
//    post_w / post_l / post_h (centre post of the stick, knob pulled off)
//    opening_d (round hole in the top plate, only for clearance checks)
//  Print the "test_ring" part first (2 min) to confirm the skirt fit.
// =====================================================================

/* [Part] */
// What to render / export
part = "boot"; // [boot, cap, test_ring, section, assembly, assembly_section, mock]

/* [Printing] */
// Fold-zone wall = 2 perimeters x 0.4 mm nozzle
wall = 0.8; // [0.6:0.1:1.2]
// Skirt / base wall (3-4 perimeters)
cuff_wall = 1.4; // [1.0:0.1:2.0]
// Segments per revolution for exported geometry
fn_round = 144; // [48:12:240]

/* [Joystick module (measure with calipers)] */
// Square steel frame / top plate width
frame_w = 16.0; // [13:0.1:18]
// Top plate height above the PCB (mock-up only)
plate_h = 12.2;
// Round opening in the top plate
opening_d = 11.0; // [9:0.5:13]
// Gimbal centre relative to the plate top (negative = below)
pivot_z = -6.7; // [-8:0.1:-4]
// Centre post cross-section (rectangular, keyed) and exposed height
post_w = 1.15;
post_l = 1.85;
post_h = 7.2;
// Potentiometer tops relative to the plate top (mock-up only)
pot_top_z = -1.0;
// Working tilt of the stick (each axis)
tilt_deg = 25; // [15:35]
// Tilt used for clearance checks (mechanical stop)
tilt_check_deg = 30; // [20:35]
// Half-angle of the cone in which the boot must not touch the stick
deadband_deg = 5; // [2:10]
// Stick push-down (button) travel
push_travel = 1.5; // [0.5:0.1:2.5]

/* [Boot] */
// Skirt stretch on the frame (pocket = frame_w - this)
cuff_interference = 0.6; // [0.2:0.1:1.2]
// Skirt engagement below the plate top (pots limit it on two sides)
skirt_depth = 2.0; // [1:0.5:4]
// Bottom lead-in chamfer of the pocket
lead_in = 0.4;
// Inner corner radius of the pocket (frame bend radius + tolerance)
skirt_corner_r = 1.0;
// Height of the solid base above the plate
base_h = 2.0; // [1.5:0.1:3]
// Inner / outer radius of the base top ring (fold root sits between them)
shelf_in_r = 8.8;
shelf_out_r = 9.8;
// Fold legs angle from vertical (45 = safe TPU overhang limit)
wall_angle = 45; // [40:60]
// Rise of the short outward leg before the crest
rise_out = 1.0; // [0.5:0.1:2]
// Crest arc radius (wall centreline)
crest_r = 1.6; // [1.2:0.1:2.5]
// Valley arc radius into the collar (wall centreline)
valley_r = 1.4; // [1.0:0.1:2.5]
// Radial collar clearance to the neck; 0 = auto from deadband_deg
collar_clear = 0; // [0:0.1:3]
// Extra clearance added to the auto value (print tolerance)
collar_extra = 0.2;
// Axial gap between collar top and cap head (push travel + cocking)
head_gap = 2.0; // [1.5:0.1:3]

/* [Cap (rigid, PLA/PETG)] */
// Neck diameter the collar floats around
neck_d = 8.0; // [6:0.5:12]
// Cap head underside height above the plate
cap_under_z = 14.0; // [11:0.5:18]
// Head diameter / height
head_d = 19.9;
head_h = 5.7;
// Socket boss around the post
boss_d = 4.4;
boss_z0 = 1.5;
boss_h = 3.0;
// Socket clearance per side and depth
socket_clear = 0.1;
socket_depth = 6.0;
// Finger dish on the head top: sphere radius and depth
dish_r = 30;
dish_depth = 1.0;
// Head top edge fillet
head_fillet = 1.5;

/* [Hidden] */
eps = 0.01;
$fn = 48;

// ---------------------------------------------------------------------
//  Derived geometry
// ---------------------------------------------------------------------
pocket_w  = frame_w - cuff_interference;     // printed skirt pocket
outer_w   = pocket_w + 2 * cuff_wall;        // skirt outside
collar_top = cap_under_z - head_gap;
clear_auto = (collar_top - 1 - pivot_z) * sin(deadband_deg) + collar_extra;
clr       = collar_clear > 0 ? collar_clear : clear_auto;
r_collar  = neck_d / 2 + clr + wall / 2;     // collar wall centreline
neck_z0   = boss_z0 + boss_h + (neck_d - boss_d) / 2;  // 45 deg cone

// Fold meridian (wall centreline), from the base top to the collar top.
a  = wall_angle;
sa = sin(a);
ca = cos(a);
r_root = (shelf_in_r + shelf_out_r) / 2;
P1 = [r_root, base_h];
P2 = P1 + [rise_out * sa / ca, rise_out];            // end of outward leg
C1 = P2 + crest_r * [-ca, sa];                       // crest centre
P3 = C1 + crest_r * [ca, sa];                        // start of inward leg
P4x = r_collar + valley_r * (1 - ca);
t_in = (P3[0] - P4x) / sa;                           // inward leg length
P4 = P3 + t_in * [-sa, ca];                          // start of valley arc
C2 = P4 + valley_r * [ca, sa];                       // valley centre
P5 = C2 + [-valley_r, 0];                            // collar bottom
n1 = 16; n2 = 8;
crest_pts  = [for (i = [0:n1]) let(th = -a + 2 * a * i / n1) C1 + crest_r * [cos(th), sin(th)]];
valley_pts = [for (i = [0:n2]) let(th = 180 + a - a * i / n2) C2 + valley_r * [cos(th), sin(th)]];
meridian = concat([[r_root, base_h - 0.6]], [P1], crest_pts, valley_pts, [[r_collar, collar_top]]);

meridian_len = rise_out / ca + crest_r * 2 * a * PI / 180 + t_in
             + valley_r * a * PI / 180 + (collar_top - P5[1]);
rest_chord = norm([r_collar, P5[1]] - P1);

// Point (r, z) fixed to the stick, after tilting the stick by ang about the pivot
function tilt_pt(p, ang) = [p[0] * cos(ang) + (p[1] - pivot_z) * sin(ang),
                            -p[0] * sin(ang) + (p[1] - pivot_z) * cos(ang) + pivot_z];
// Inner face of the base at height z (0..base_h), side midpoint
function base_inner_r(z) = pocket_w / 2 + (shelf_in_r - pocket_w / 2) * max(0, min(1, z / base_h));

neck_corner = tilt_pt([neck_d / 2, neck_z0], tilt_check_deg);
boss_corner = tilt_pt([boss_d / 2, boss_z0], tilt_check_deg);
collar_shift = (collar_top - 1 - pivot_z) * sin(tilt_deg);
engage_deg = asin(clr / (collar_top - 1 - pivot_z));

echo(str("Boot: skirt pocket ", pocket_w, " sq, outside ", outer_w, " sq, height ", -skirt_depth, "..", collar_top));
echo(str("Collar: ID ", 2 * (r_collar - wall / 2), " OD ", 2 * (r_collar + wall / 2),
         " Z ", P5[1], "..", collar_top, "  clearance ", clr, " -> first contact at ", engage_deg, " deg"));
echo(str("Fold: crest outer r ", C1[0] + crest_r + wall / 2, " at Z ", C1[1],
         ", meridian ", meridian_len, " mm, rest chord ", rest_chord, " mm"));
echo(str("At ", tilt_deg, " deg the neck drags the collar ", collar_shift - clr, " mm sideways"));
echo(str("Clearance check at ", tilt_check_deg, " deg: neck corner r ", neck_corner[0], " z ", neck_corner[1],
         " vs base inner r ", base_inner_r(neck_corner[1]),
         "; boss corner r ", boss_corner[0], " z ", boss_corner[1], " vs opening r ", opening_d / 2));
if (collar_top - P5[1] < 1.0)
    echo("WARNING: collar shorter than 1 mm - raise cap_under_z or reduce crest_r/valley_r");
if (t_in < 0)
    echo("WARNING: collar wider than the crest - reduce neck_d or increase shelf radii");

// ---------------------------------------------------------------------
//  2D helpers
// ---------------------------------------------------------------------
module rsq(s, r) { offset(r = r) square(s - 2 * r, center = true); }
module slab(z, h = eps) { translate([0, 0, z]) linear_extrude(h) children(); }

// Stroke a polyline with a round pen -> uniform normal thickness w
module stroke2d(pts, w) {
    for (i = [0:len(pts) - 2])
        hull() {
            translate(pts[i])     circle(d = w, $fn = 24);
            translate(pts[i + 1]) circle(d = w, $fn = 24);
        }
}
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

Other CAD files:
versions/v002-20260911-145403/ky023_boot.scad
versions/v003-20260911-150205/ky023_boot.scad
versions/v004-20260911-150845/ky023_boot.scad
versions/v005-20260911-152531/ky023_boot.scad
versions/v006-20260911-153629-printed/ky023_boot.scad
versions/v007-20260911-160759/ky023_boot.scad
versions/v008-20260911-191836/ky023_boot.scad
versions/v009-20260911-192050/ky023_boot.scad
versions/v010-20260911-194600/ky023_boot.scad
versions/v011-20260911-202151/ky023_boot.scad
versions/v012-20260911-202330/ky023_boot.scad
versions/v013-20260911-203047/ky023_boot.scad
versions/v014-20260911-203900/ky023_boot.scad
versions/v015-20260911-204101/ky023_boot.scad
versions/v016-20260911-204253/ky023_boot.scad
versions/v017-20260911-205507/ky023_boot.scad
versions/v018-20260911-205704/ky023_boot.scad
versions/v019-20260911-205929-printed/ky023_boot.scad
versions/v020-20260911-232959/ky023_boot.scad
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

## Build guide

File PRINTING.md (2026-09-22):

**English** · [Українська](PRINTING.uk.md)

# Printing, assembly, casting

A working document for whoever prints this. What it is and how it works —
[README.md](README.md); parameters and internal mechanics — [MODEL.md](MODEL.md).

## What you need

| | |
|---|---|
| OpenSCAD | 2021+ (tested on 2026.09), Manifold backend |
| Python 3 | the automatic checks during a render |
| Printer | 0.4 nozzle, bed from 70 × 50 mm |
| Filament | TPU — boot and gasket; PETG or ASA — box and lid; PLA or PETG — ring and cap |
| Fasteners | 4 × M3×6 (board to standoffs), 4 × M3×10 (lid to box) |
| Glue | cyanoacrylate or epoxy — to glue the cap head onto the stem |

## Before the first print, check your module

The KY-023 mounting hole grid is not in any datasheet, and the community mock-up
contradicts itself. The model uses values measured on a real HW-504, but **the
board hole pitch is unverified** — for M3 standoffs a 1 mm miss is already
critical. Measure the hole pitch and the stem height under the knob on your own
board; if they differ, it is fixed with parameters: [MODEL.md](MODEL.md).

`ky023_mock.stl` helps you check the joystick position on the board — it is a
mock-up, not for printing.

## Getting the STLs

```
./render.sh
```

Creates `versions/vNNN-date-time/` and puts every STL, PNG and `render.log`
there. File names start with the version number (`v027_ky023_box.stl`) so that
the slicer shows which render a part came from. Nothing in the code needs editing
for this.

At the end of `render.log` are the automatic checks: every STL must be one closed
body and must print without supports. If there is a `FAIL` there, better not take
it to the slicer.

## What to print

One of each:

| Part | File `vNNN_…` | Filament | How it sits on the bed |
|---|---|---|---|
| Boot with grommet | `ky023_boot.stl` | TPU | grommet down, corrugation up |
| Lid gasket | `ky023_gasket.stl` | TPU | flat, groove up |
| Expander ring | `ky023_ring.stl` | PLA/PETG | flange on the bed |
| Cap: head | `ky023_cap_head.stl` | PLA/PETG | disc on the bed |
| Cap: stem | `ky023_cap_stem.stl` | PLA/PETG | boss on the bed, **with a brim** |
| Box | `ky023_box.stl` | PETG/ASA | upside down, panel on the bed |
| Lid | `ky023_lid.stl` | PETG/ASA | outer face on the bed |

Every STL is already rotated the way it prints — just drop it into the slicer.

Also in the folder, but **not for printing**: `ky023_mock.stl` — the board mock-up;
`ky023_boot_cast.stl` — what the silicone casting should look like. And
`ky023_boot_deep.stl` is the second bellows option (one deep fold instead of two
shallow ones): softer on paper, not yet verified in plastic. You can print both
and compare them on the same module — every other part is identical.

## Print settings

**TPU (boot, gasket).** Line width 0.42, layer 0.15–0.2, 15–20 mm/s, fan 40–60 %,
brim 3 mm. Infill 0 % for the boot and 100 % for the gasket, turn `gap fill` off,
turn "detect thin walls" / Arachne on. The corrugation wall is a single nozzle
pass (0.46 mm), so after slicing look through the layers at the bend heights:
there must be no empty layers (`render.log` catches this as `thin wall`).

**Box and lid (PETG/ASA).** For sealing: 4 perimeters, 6 solid panel layers, flow
102–105 %. The sealing rib on the box rim is printed by the last layers as two
0.4 mm lines.

**Cap and ring (PLA/PETG).** 3 perimeters. The stem must have a brim — it is a
Ø6.8 × 26 mm column. No supports anywhere: every bridge is ≤ 8 mm, chamfers 45°.

## Assembly

1. Solder the cable, screw the board to the lid standoffs with 4 × M3×6. Take the
   cable out through a hole potted with compound (there is no gland hole by
   default).
2. Remove the stock bell knob from the joystick.
3. Fit the gasket onto the rib on the box rim by its groove — it holds itself
   there. Bring the lid with the board in from below (the joystick goes under the
   panel opening) and tighten 4 × M3×10 crosswise.
4. Push the cap stem, boss down, through the top opening of the boot and stretch
   the boot bead onto the stem groove (Ø18.5, ~6 % interference) so it seats on
   the flange lip.
5. Lower the boot with the stem onto the module: the stem seats on the joystick
   shaft (a socket with flats, 2 orientations), the grommet enters the panel
   opening until the lip clicks under the panel, and the cone comes flush with the
   panel.
6. From inside the box, insert the expander ring nose-up into the grommet opening
   and push until the flange seats under the lip. It passes the lip easily; you
   only need to push the last ~0.7 mm, until the band sits under the grommet rib.
   If it is too tight or, conversely, loose — that is a parameter, see
   [MODEL.md](MODEL.md).
7. Glue the cap head onto the stem plug (Ø8, 0.2 mm clearance). Its flat bottom
   covers the groove with the bead.

## Casting the boot in silicone (optional)

A printed boot runs into a minimum wall: 0.46 mm is one nozzle pass, it does not
get thinner, and stiffness grows as the cube of thickness. Silicone gets around
that with the material — A20 is roughly 50 times softer than TPU 95A, so even a
1.2 mm wall gives a boot about three times softer (with A10, about five times).
The geometry is the same: the same grommet, bead, ring and stem, both bellows
profiles.

The mould is calculated and verified by boolean tests (`check_fit.scad`), but not
yet printed and not yet poured.

To print (PLA or PETG, 3 perimeters, 20–30 % infill):

| Part | File `vNNN_…` | Qty |
|---|---|---|
| Shell half | `ky023_mould_shell.stl` | **2** (identical) |
| Core, lower half | `ky023_mould_core_lower.stl` | 1 |
| Core, upper half | `ky023_mould_core_upper.stl` | 1 |
| Shell dowels | `ky023_mould_dowel.stl` | **2** |
| Core pin | `ky023_mould_pin.stl` | 1 |

For the deep bellows, the same files with `_deep` (the core pin is shared).
The shell prints parting-plane up, no supports needed.
You will also need: 4 × M4×50 with nuts (40 mm clamp), a 10 ml syringe, and
release agent or thin petroleum jelly.

**How much silicone.** The part itself is 2.85 cm³ (standard bellows) or 3.02
(`deep`); together with the riser and the ports, the mould takes 3.6 / 3.8 ml.
Mix 5–6 ml: the rest stays in the syringe and the cup.

Procedure:

1. **Check compatibility first.** Platinum silicone is inhibited by some plastics
   — put a smear on an offcut of the same filament and see whether it cures within
   a day. Finding this out on a full mould is an expensive lesson. Then release
   agent on every surface.
2. Lower core half into the bottom of the shell, then the pin, then the upper half
   on top; its boss comes out through the roof of the shell.
3. Clamp the halves with 4 × M4 through the ears; the dowels centre them.
4. Degas the silicone and syringe it into the lower port until it comes out of the
   second port and the vent holes at the top.
5. After curing: bolts off, split the shell, pull the upper core half up by its
   boss and the lower one down.
6. Trim the flash along the parting line (carefully on the grommet — that is a
   sealing surface) and the riser ring on top.

You can check the result against `ky023_boot_cast.stl` — that is what the mould
should produce.

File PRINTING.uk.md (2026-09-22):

[English](PRINTING.md) · **Українська**

# Друк, збирання, лиття

Робочий документ для того, хто це друкує. Що воно таке і як влаштоване —
[README.uk.md](README.uk.md); параметри і внутрішня механіка — [MODEL.uk.md](MODEL.uk.md).

## Що потрібно

| | |
|---|---|
| OpenSCAD | 2021+ (перевірено на 2026.09), бекенд Manifold |
| Python 3 | автоматичні перевірки під час рендеру |
| Принтер | сопло 0.4, стіл від 70 × 50 мм |
| Пластик | TPU — сильфон і прокладка; PETG або ASA — коробка й кришка; PLA або PETG — кільце й ковпачок |
| Кріплення | 4 × M3×6 (плата до стійок), 4 × M3×10 (кришка до коробки) |
| Клей | ціакрин або епоксидка — приклеїти головку ковпачка на шток |

## Перед першим друком звір свій модуль

Сітки монтажних отворів KY-023 немає в datasheet-ах, а спільнотний макет
суперечить сам собі. У моделі стоять значення, зміряні на реальному HW-504,
але **крок отворів плати не перевірений** — для стійок M3 промах в 1 мм уже
критичний. Зміряй на своїй платі крок отворів і висоту штока під шапкою; якщо
не збігається, це правиться параметрами: [MODEL.uk.md](MODEL.uk.md).

Звірити положення джойстика на платі допомагає `ky023_mock.stl` — макет плати,
не для друку.

## Отримати STL

```
./render.sh
```

Створює `versions/vNNN-дата-час/` і кладе туди всі STL, PNG і `render.log`.
Імена файлів починаються з номера версії (`v027_ky023_box.stl`), щоб у слайсері
було видно, з якого рендера деталь. Нічого правити в коді для цього не треба.

У `render.log` наприкінці — автоматичні перевірки: кожен STL має бути одним
замкненим тілом і друкуватися без підтримок. Якщо там `FAIL`, у слайсер краще
не нести.

## Що друкувати

Усе по одній штуці:

| Деталь | Файл `vNNN_…` | Пластик | Як кладеться на стіл |
|---|---|---|---|
| Сильфон із громметом | `ky023_boot.stl` | TPU | громметом униз, гофрою догори |
| Прокладка кришки | `ky023_gasket.stl` | TPU | плоско, канавкою догори |
| Розпірне кільце | `ky023_ring.stl` | PLA/PETG | фланцем на стіл |
| Ковпачок: головка | `ky023_cap_head.stl` | PLA/PETG | диском на стіл |
| Ковпачок: шток | `ky023_cap_stem.stl` | PLA/PETG | бобишкою на стіл, **з каймою** |
| Коробка | `ky023_box.stl` | PETG/ASA | догори дном, панеллю на стіл |
| Кришка | `ky023_lid.stl` | PETG/ASA | зовнішньою площиною на стіл |

Усі STL уже повернуті так, як друкуються, — просто кинь у слайсер.

Ще в папці лежать, але **не для друку**: `ky023_mock.stl` — макет плати;
`ky023_boot_cast.stl` — як має виглядати силіконова відливка. А
`ky023_boot_deep.stl` — другий варіант гофри (одна глибока складка замість двох
дрібних): на папері м'якший, ще не перевірений у пластику. Можна надрукувати
обидва й порівняти на тому самому модулі — решта деталей однакова.

## Налаштування друку

**TPU (сильфон, прокладка).** Ширина лінії 0.42, шар 0.15–0.2, 15–20 мм/с,
обдув 40–60 %, кайма 3 мм. Заповнення 0 % для сильфона і 100 % для прокладки,
`gap fill` вимкнути, «detect thin walls» / Arachne увімкнути. Стінка гофри —
один прохід сопла (0.46 мм), тож після слайсингу переглянь шари на висотах
згинів: порожніх шарів бути не має (`render.log` ловить це як `thin wall`).

**Коробка і кришка (PETG/ASA).** Для герметичності: 4 периметри, 6 суцільних
шарів панелі, потік 102–105 %. Ущільнювальне ребро на бортику коробки
друкується останніми шарами двома лініями по 0.4 мм.

**Ковпачок і кільце (PLA/PETG).** 3 периметри. Шток — обов'язково з каймою, це
стовпчик Ø6.8 × 26 мм. Підтримок не треба ніде: усі містки ≤ 8 мм, фаски 45°.

## Збирання

1. Припаяти кабель, прикрутити плату до стійок кришки 4 × M3×6. Кабель вивести
   крізь отвір, залитий компаундом (отвору під сальник за замовчуванням немає).
2. Зняти штатну шапку-дзвін із джойстика.
3. Надіти прокладку канавкою на ребро бортика коробки — вона тримається сама.
   Завести кришку з платою знизу (джойстик заходить під отвір панелі),
   затягнути 4 × M3×10 навхрест.
4. Просунути шток ковпачка бобишкою вниз крізь верхній отвір сильфона і
   натягнути валик сильфона на канавку штока (Ø18.5, натяг ~6 %), щоб він ліг
   на губу фланця.
5. Опустити сильфон зі штоком на модуль: шток сідає на шток джойстика (гніздо
   з лисками, 2 орієнтації), громмет входить в отвір панелі до клацання губи
   під панеллю, конус стає врівень із панеллю.
6. Зсередини коробки вставити розпірне кільце носком догори в отвір громмета і
   дотиснути, поки фланець не сяде під губу. Крізь губу воно проходить легко;
   тиснути треба тільки останні ~0.7 мм, поки поясок не стане під ребро
   громмета. Якщо туго або навпаки бовтається — це правиться параметром, див.
   [MODEL.uk.md](MODEL.uk.md).
7. Приклеїти головку ковпачка на заглушку штока (Ø8, зазор 0.2 мм). Її плоский
   низ накриває канавку з валиком.

## Лиття сильфона силіконом (опційно)

Надрукований сильфон упирається в мінімальну стінку: 0.46 мм — це один прохід
сопла, тонше не буває, а жорсткість росте як куб товщини. Силікон обходить це
матеріалом — A20 приблизно в 50 разів м'якший за TPU 95A, тож навіть стінка
1.2 мм дає ~втричі м'якший сильфон (на A10 — ~вп'ятеро). Геометрія та сама:
той самий громмет, валик, кільце і шток, обидві гофри.

Молд рахований і перевірений булевими тестами (`check_fit.scad`), але ще не
друкований і не заливаний.

Надрукувати (PLA або PETG, 3 периметри, заповнення 20–30 %):

| Деталь | Файл `vNNN_…` | Шт. |
|---|---|---|
| Половина мушлі | `ky023_mould_shell.stl` | **2** (однакові) |
| Стрижень, нижня половина | `ky023_mould_core_lower.stl` | 1 |
| Стрижень, верхня половина | `ky023_mould_core_upper.stl` | 1 |
| Штифти мушлі | `ky023_mould_dowel.stl` | **2** |
| Штифт стрижня | `ky023_mould_pin.stl` | 1 |

Для глибокої гофри — ті самі файли з `_deep` (штифт стрижня спільний).
Мушля друкується площиною розняття догори, підтримок не треба.
Ще знадобиться: 4 × M4×50 з гайками (стяг 40 мм), шприц на 10 мл, роздільник
або тонкий вазелін.

**Скільки силікону.** Сама деталь — 2.85 см³ (звичайна гофра) або 3.02 (`deep`);
разом із ризером і портами молд бере 3.6 / 3.8 мл. Мішати варто 5–6 мл: решта
лишиться у шприці й посудині.

Порядок:

1. **Спершу перевірити сумісність.** Платиновий силікон інгібується деякими
   пластиками — мазок на обрізку того самого прутка, чи застигне за добу.
   Дізнаватися про це на повному молді — дороге задоволення. Потім роздільник
   на всі поверхні.
2. Нижню половину стрижня — у дно мушлі, штифт, зверху верхню половину; її
   бобишка виходить крізь дах мушлі.
3. Стягнути половини 4 × M4 через вуха; штифти центрують.
4. Дегазувати силікон і шприцом у нижній порт, поки не полізе з другого порту
   і з вентиляційних отворів угорі.
5. Після полімеризації: болти геть, розняти мушлю, верхню половину стрижня
   витягнути вгору за бобишку, нижню — вниз.
6. Обрізати облой по лінії розняття (на громметі акуратно — це ущільнювальна
   поверхня) і кільце ризера зверху.

Звірити результат можна з `ky023_boot_cast.stl` — це те, що молд має дати.

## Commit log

2026-09-22 Герметичний корпус KY-023: модель, перевірки, документація
    Один параметричний файл OpenSCAD на всі сім деталей і молд під лиття,
    скрипти рендеру і чотири автоматичні перевірки (сітка, навіси, об'єм,
    порівняння версій), документація в трьох рівнях: README — вітрина,
    PRINTING — друк і збирання, MODEL — довідник по моделі.
    У versions/ лежать копії сорсів кожного рендера; STL, PNG і логи
    ігноруються, крім docs/img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
    [check_fit.scad, ky023_boot.scad]
2026-09-22 README англійською за замовчуванням, український оригінал поруч
    GitHub показує README.md першим, тож англійська версія стає типовою,
    а український текст переїхав у README.uk.md без змін. Угорі кожного —
    перемикач на іншу мову.
    PRINTING.md і MODEL.md лишаються українською і тепер посилаються на
    README.uk.md; англійський README попереджає про це одразу під заголовком.
2026-09-22 PRINTING і MODEL теж англійською, українські оригінали поруч
    Тепер усі три документи двомовні за тією самою схемою, що й README:
    англійська — типова назва, яку відкриває GitHub, *.uk.md — оригінал.
    Посилання не перетинають мову: англійський документ веде на англійські,
    український — на *.uk.md.
    З англійського README знято попередження, що PRINTING і MODEL лише
    українською, — воно більше не відповідає дійснос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
2026-10-02 Added photo of 3D printed objects
